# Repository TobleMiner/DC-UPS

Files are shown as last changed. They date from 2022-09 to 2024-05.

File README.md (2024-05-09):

DC uninterruptible power supply
===============================

This repository contains the design files for a DC uninterruptible power
supply well suited to run network appliances like small switches, home
routes and WLAN access points.

**I would not recommend ordering RevC yet as it is still untested.**  
**I would not recommend ordering RevB yet as there are still some issues with the current design.
See [Rev B issues](https://github.com/TobleMiner/DC-UPS#rev-b-issues) below.**

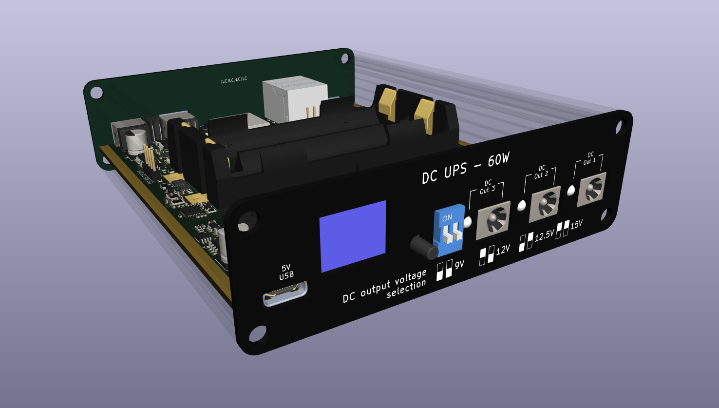
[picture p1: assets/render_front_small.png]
Render of the device


# Features

 - 3 DC outputs
 - Selectable output voltage (9V/12V/12.5V/15V)
 - USB-C power output (5V only, 3A)
 - Builtin, easy to replace batteries (2x Li-Ion 18650)
 - Builtin Prometheus-exporter with comprehensive metrics
 - Open Source firmware (ESP32-based, esp-idf framework)
 - Easy software updates via back USB port

# Construction

The mechanical construction of the DC UPS is based on 4 assemblies:
 - Hammond Manufacturing 1455L1201BK aluminum case
 - Main PCB
 - Aluminum core PCB front panel
 - Aluminum core PCB rear panel

The three PCBs have been optimized for manufacturing through JLCPCB.  
The main PCB is also designed to be suitable for assembly through JLCPCB.  

The relevant fabrication files are located in `fab`.  

For final assembly it is recommended to countersink the screw holes in
front and rear panel. This will allow the screws included with the case to
sit flush.

## Main PCB assembly

When using the JLCPCB assembly service only a very limited number of
components needs to be assembled by hand:
 - Battery holder B1
 - OLED display U17

## Thermals

For better thermal management I would highly recommend to install a thick,
generously sized thermal pad below U4 and L2 contacting the bottom case if
using the UPS DC outputs beyond 40W output power.

# Firmware

The DC UPS is running Open Source firmware. Firmware source can be found on
GitHub here: [https://github.com/TobleMiner/dc-ups-firmware](https://github.com/TobleMiner/dc-ups-firmware)

# Why?

For a long time I was running the core of my home network (a cable modem,
router and switch) off a normal line-interactive AC UPS.  
This was never ideal for a number of reasons. First of all the UPS was
using sealed lead acid batterys. The UPS did not seem to treat those too
kindly and ended up degrading them beyond the point of useful capacity
within 2 - 5 years, depending on quality of the battery.  
Also I noticed that the UPS was always getting somewhat warm, suggesting
high idle power consumption. In this particular setup the core network
components only use about 12W. The AC UPS alone already used 10W while
idle. Quite the waste of power.  
Another worrying factor was overall system reliability. With the AC UPS
there were three seperate wall warts in use, each powering a single
device. Powering all network compoenents with DC directly this is down
to just one wall wart at the power input of the UPS itself.  
Additionally I was never quite happy with the monitoring options offered
by the AC UPS. While it was equipped with a USB port for monitoring the
available metrics were minimal. The DC UPS offers an Ethernet port and
hosts a Prometheus exporter offering all kinds of metrics relating to
power input and output, temperatures, battery health and battery
management internals.  
Finally the DC UPS is a lot smaller than available AC UPS options. The
following picture shows a comparison between the AC UPS I have been using
before and the DC UPS:  

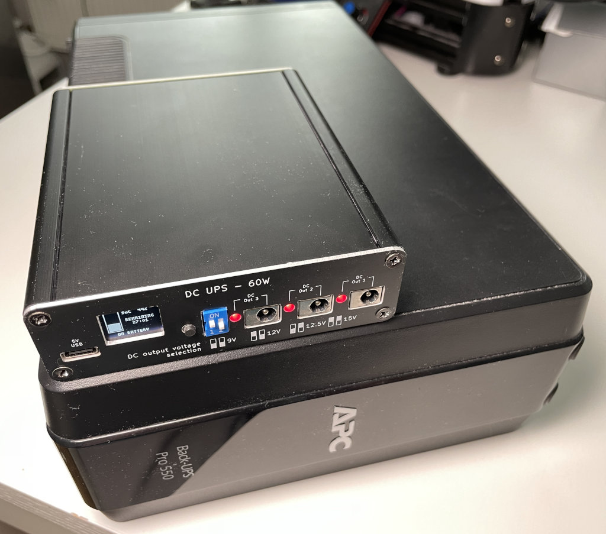
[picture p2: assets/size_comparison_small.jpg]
Size comparison between AC UPS and DC UPS. DC UPS is way smaller


# Rev B issues

Rev B is still more of a prototype than I'd like.
This is the list of currently know issues:
 - DCDC U4 startup is too slow on power failure, remove Q13
 - R47 and R48 are too high resistance for effective testing

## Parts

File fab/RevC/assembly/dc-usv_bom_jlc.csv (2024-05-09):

Comment | Designator | Footprint | LCSC Part Number
100nF | C1,C2,C3,C4,C5,C13,C16,C24,C25,C26,C30,C42,C45,C47,C48,C51,C59,C65,C66,C68,C96,C99,C101,C71,C73,C77,C78,C79,C81,C86,C88,C92,C93 | C_0402_1005Metric | C1525
2.2uF | C6,C53,C103 | C_0603_1608Metric | C23630
100nF HV | C7,C8,C9,C10,C11,C14,C34,C41,C43,C44,C46,C54,C72,C85,C87 | C_0603_1608Metric | C14663
1uF | C12,C17,C18,C27,C60,C62,C63,C64,C97,C98,C83 | C_0402_1005Metric | C52923
100pF | C15,C67 | C_0402_1005Metric | C1546
47nF HV | C19 | C_0603_1608Metric | C1622
10uF | C20,C21,C22,C23,C35,C36,C37 | C_0805_2012Metric | C15850
22uF | C28,C29,C31,C38,C39,C40,C94,C52,C55,C56,C57,C70,C74,C75 | C_0805_2012Metric | C602037
4.7uF | C32 | C_0402_1005Metric | C23733
680pF | C33 | C_0603_1608Metric | C1630
220uF | C49,C50,C80,C84 | CP_Elec_6.3x7.7 | C340768
18pF | C58,C76 | C_0402_1005Metric | C1549
470pF | C61 | R_0402_1005Metric | C1537
1nF 500V | C69,C82,C89 | C_1206_3216Metric | C35216
20pF | C90,C91 | C_0402_1005Metric | C1554
10uF LV | C100 | C_0402_1005Metric | C15525
4.7uF HV | C102 | C_0603_1608Metric | C19666
22nF | C104,C95,C105 | C_0402_1005Metric | C1532
1N4148WS | D1,D2,D3 | D_SOD-323 | C2128
BAV70 | D4 | SOT-23 | C68978
SS36 | D5 | D_SMC | C35722
P6SMB18CA | D6,D9,D10,D11 | D_SMB | C384916
RED | D8,D12,D13,D14 | LED_Indicator_RED_MHK1373CRBDT | C417352
B5819W | D15 | D_SOD-123 | C8598
P6SMB6.8CA | D16,D7 | D_SMB | C78395
YEL | D17,D21 | LED_0603_1608Metric | C72038
RED | D18,D22 | LED_0603_1608Metric | C2286
GRN | D19,D20 | LED_0603_1608Metric | C2994781
10A | F1 | Fuse_1206_3216Metric | C242475
5A | F2,F3,F4 | Fuse_1206_3216Metric | C377290
Output 2.0mm | J1,J2,J3 | BarrelJack_2.0mm_DC-044B | C397334
HanRun_HR911105A | J5 | RJ45_Hanrun_HR911105A | C12074
USB_C_Receptacle_USB2.0 | J6,J9 | USB_C_Receptacle_Palconn_UTC16-G | C167321
Input 2.0mm | J7 | BarrelJack_2.0mm_DC-044B | C397334
Input 2.5mm | J8 | BarrelJack_2.5mm_DC-044K-D025 | C963204
2.2uH | L1 | L_Taiyo-Yuden_MD-4040 | C98361
1uH | L2 | L_Bourns_SRP7028A_7.3x6.6mm | C439005
4.7uH | L3 | L_1008_2520Metric | C91237
4.7uH | L4 | L_Bourns_SRP7028A_7.3x6.6mm | C76857
AON7544 | Q1,Q3,Q4,Q5 | DFN-8-FET_3x3mm_P0.65mm | C315567
AO3401A | Q2,Q25 | SOT-23 | C15127
CSD17308Q3 | Q6,Q7 | DFN-8-FET_3x3mm_P0.65mm | C294987
AO4407A | Q8,Q10,Q19,Q21,Q23,Q32,Q35,Q38 | SOIC-8_3.9x4.9mm_P1.27mm | C167517
MMBT5401 | Q9,Q24 | SOT-23 | C8326
MMBT3904 | Q12,Q18,Q28,Q29,Q30,Q33,Q36 | SOT-23 | C20526
AO3400A | Q17 | SOT-23 | C20917
2N7002 | Q26,Q11,Q14,Q15,Q16,Q20,Q22,Q31,Q34,Q37 | SOT-23 | C8545
1mR | R1 | R_1206_3216Metric | C76287
100R | R2,R3,R130,R69,R122,R123,R99,R100 | R_0402_1005Metric | C25076
100R 0805 | R4,R5,R11 | R_0805_2012Metric | C17408
10MR | R6,R10,R13 | R_0402_1005Metric | C26082
300R | R7 | R_1206_3216Metric | C17887
5.1k | R8,R9,R12,R18,R22,R120,R124,R125,R97,R98 | R_0402_1005Metric | C25905
10k | R14,R95,R128,R129,R20,R119,R121,R93,R51,R53,R56,R57,R58,R60,R61,R62,R63,R65,R118,R127,R132,R83,R84,R126,R103,R113,R114,R115 | R_0402_1005Metric | C25744
100kR | R15,R26,R27,R29,R31,R33,R35,R41,R46,R49,R50,R94,R131,R52,R54,R59,R74,R116,R76,R77,R86,R87,R101,R102,R104,R105,R106,R107,R108,R109,R110,R111,R112 | R_0402_1005Metric | C25741
39kR | R16 | R_0402_1005Metric | C25783
18kR | R17,R21 | R_0402_1005Metric | C25762
10mR | R19,R25,R42,R43,R81,R90 | R_0805_2012Metric | C270927
10R | R23,R24 | R_0402_1005Metric | C25077
150k | R28 | R_0402_1005Metric | C25755
56kR | R30,R92 | R_0402_1005Metric | C25796
47kR | R32 | R_0603_1608Metric | C25819
180kR | R34 | R_0603_1608Metric | C22827
220kR | R36 | R_0402_1005Metric | C25767
1R | R37,R38,R44,R45,R80,R82,R89,R91 | R_0402_1005Metric | C25086
750kR | R39 | R_0603_1608Metric | C23240
15kR | R40 | R_0402_1005Metric | C25756
50R | R47,R48 | R_2512_6332Metric | C25487
22kR | R55 | R_0402_1005Metric | C25768
1.5kR | R64,R79 | R_0402_1005Metric | C25867
50R | R66,R68,R70,R71 | R_0402_1005Metric | C25120
12kR | R67,R78 | R_0402_1005Metric | C25752
330R | R72,R73 | R_0402_1005Metric | C25104
100kR | R75,R85,R96 | R_1206_3216Metric | C17900
10R | R88 | R_1206_3216Metric | C17903
390kR | R117 | R_0603_1608Metric | C23150
SW_DIP_x02 | SW1 | PinHeader_2x02_P2.54mm_Vertical | C692490
SW_Push | SW2 | x-1825027-x | C266183
10k | TH1,TH2 | R_0402_1005Metric | C279801
BQ40z50-R2 | U1 | VQFN-32-4.1x4.1-EP-1.4 | C179743
LM75B | U2,U7,U13 | MSOP-8_3x3mm_P0.65mm | C2837470
BQ24715 | U3 | QFN-20-1EP_3.5x3.5mm_P0.5mm_EP2x2mm_ThermalVias | C276341
TPS61178x | U4 | VSON-HR-13 | C127918
INA219AxD | U5,U6,U14,U15 | SOIC-8_3.9x4.9mm_P1.27mm | C138706
SY8120B1ABC | U8 | SOT-23-6 | C88474
ESP32-WROOM-32E | U9 | ESP32-WROOM-32 | C701342
LAN8720A | U10 | QFN-24-1EP_4x4mm_P0.5mm_EP2.6x2.6mm | C45223
74HC595 | U11 | SOIC-16_3.9x9.9mm_P1.27mm | C5947
SY8105 | U12 | TSOT-23-6 | C178247
CH340C | U16 | SOIC-16_3.9x9.9mm_P1.27mm | C84681
N066-6448TSWEG03-H28 | U17 | N066-6448TSWEG03-H28 | C2890608
SRV05-4 | U18 | SOT-23-6 | C85364

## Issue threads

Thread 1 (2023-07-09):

Provide header for unused GPIO

t-aus-m, 2023-07-09:
Hello there,

I really like the idea of this UPS, and I'd like to build it myself someday. However, I think there is one feature that is missing that would make this project even more versatile: As fas as I understood the schematics, there are still unused GPIOs left on the ESP32 that could be used to extend the use of the device even further.
Would it be possible to add a header, maybe even accessible from the outside to the device? For example, I'd use this header to be able to safely shut down my NAS in the event that the UPS is nearly empty.

Thanks for that awesome project!
Cheers

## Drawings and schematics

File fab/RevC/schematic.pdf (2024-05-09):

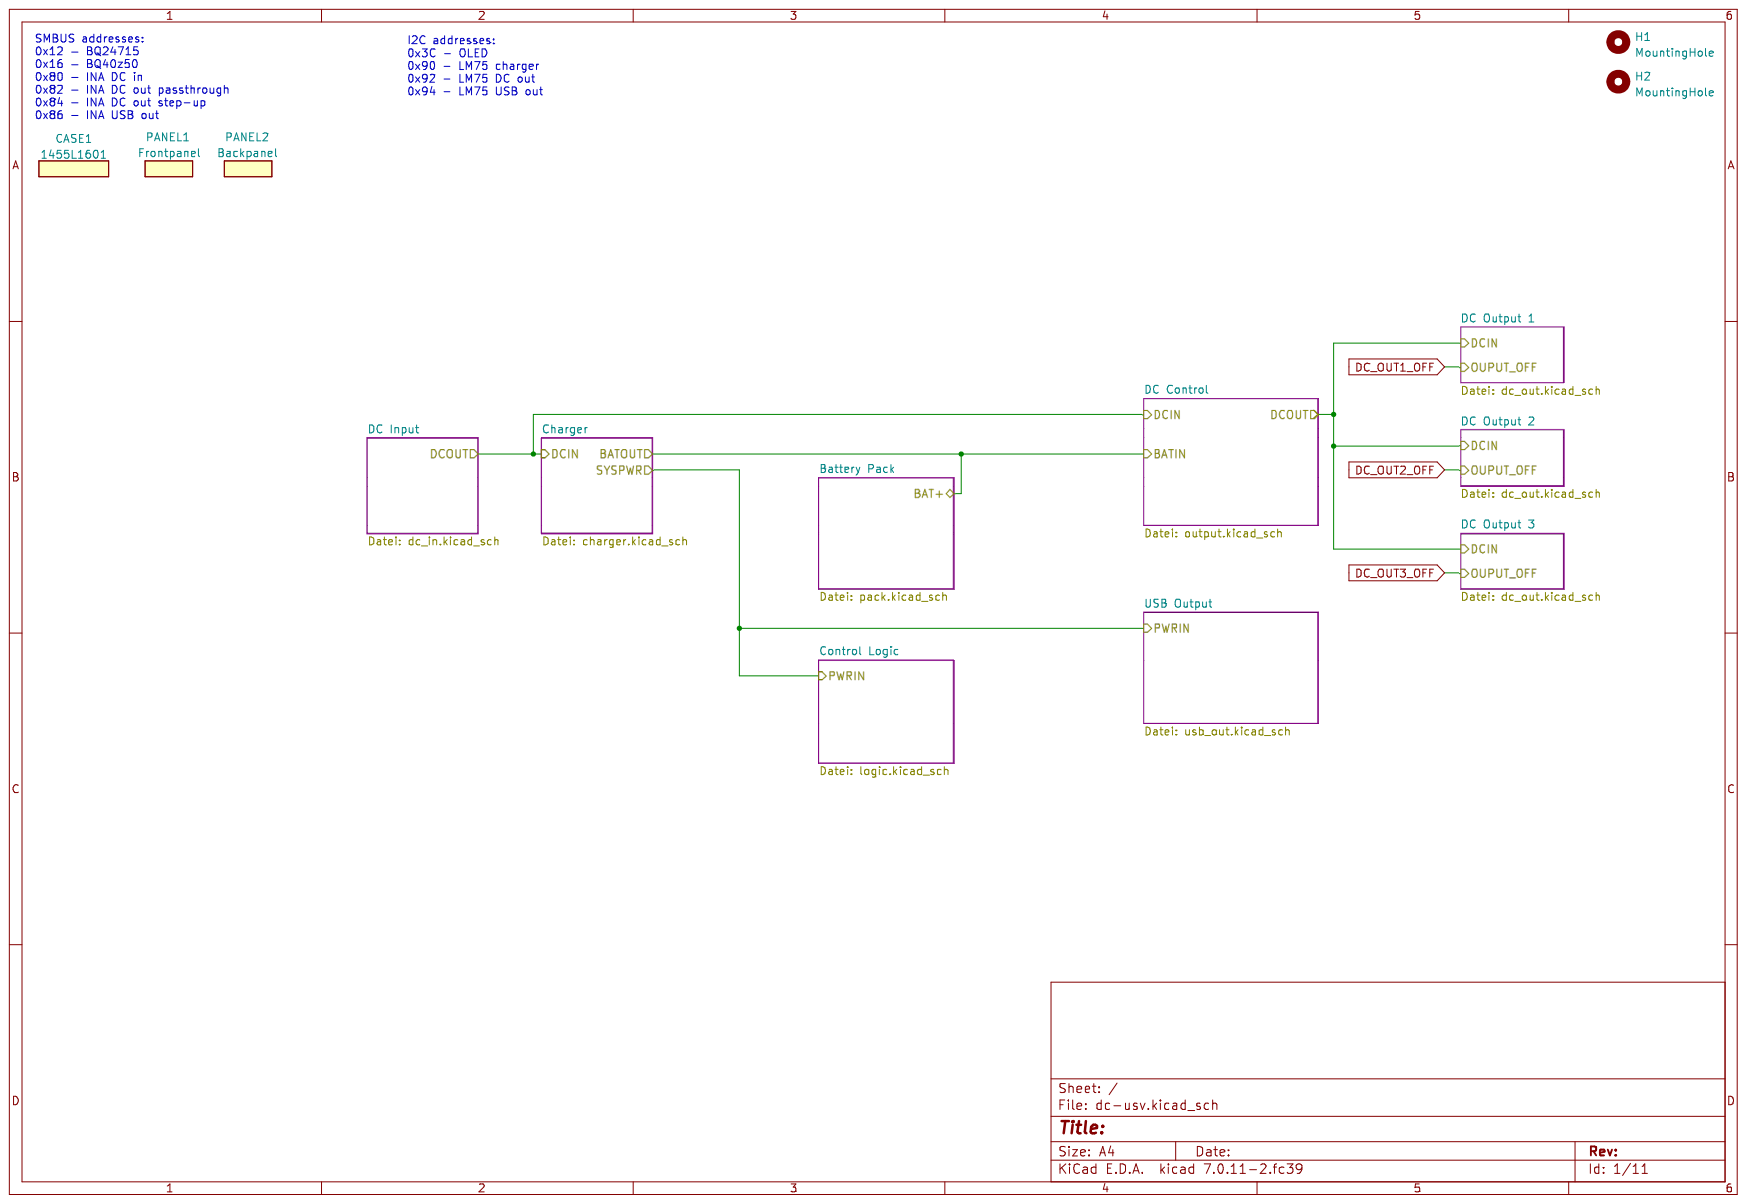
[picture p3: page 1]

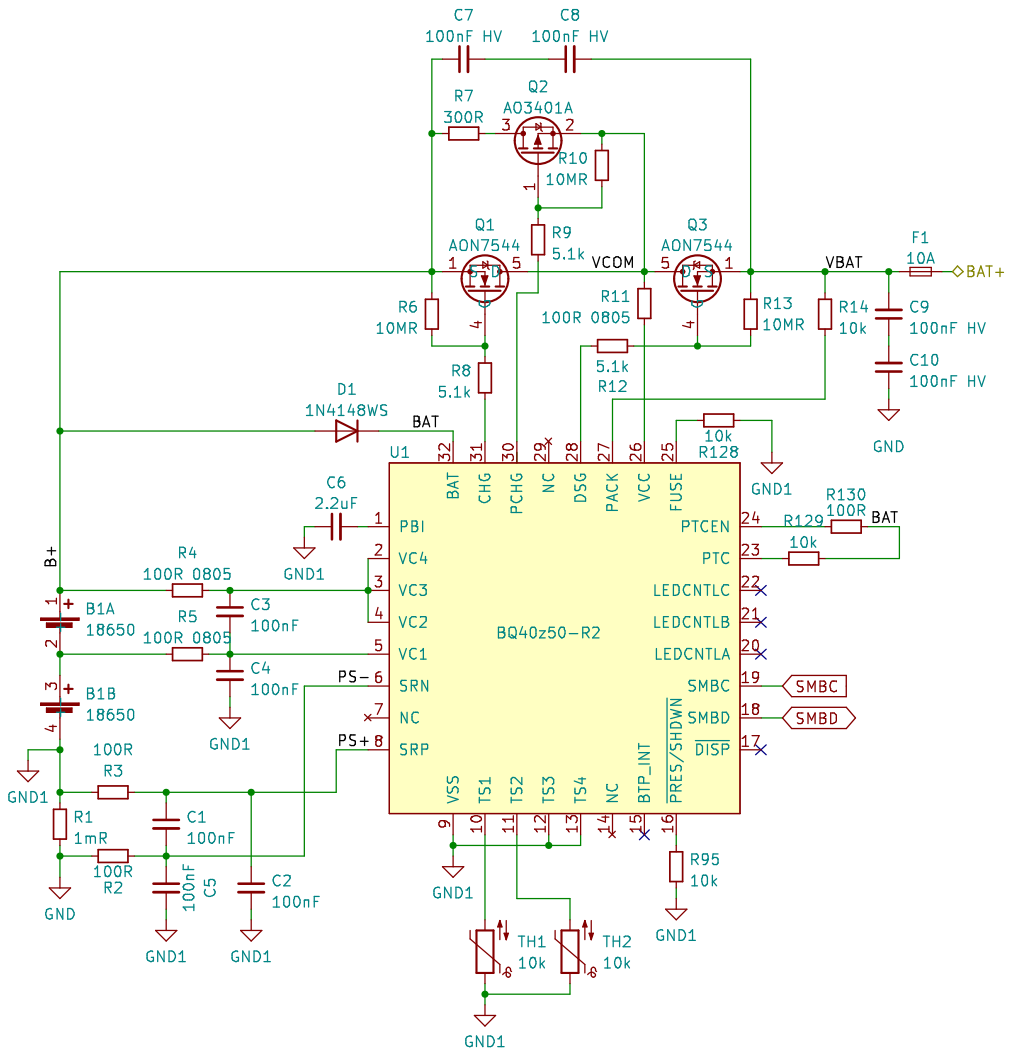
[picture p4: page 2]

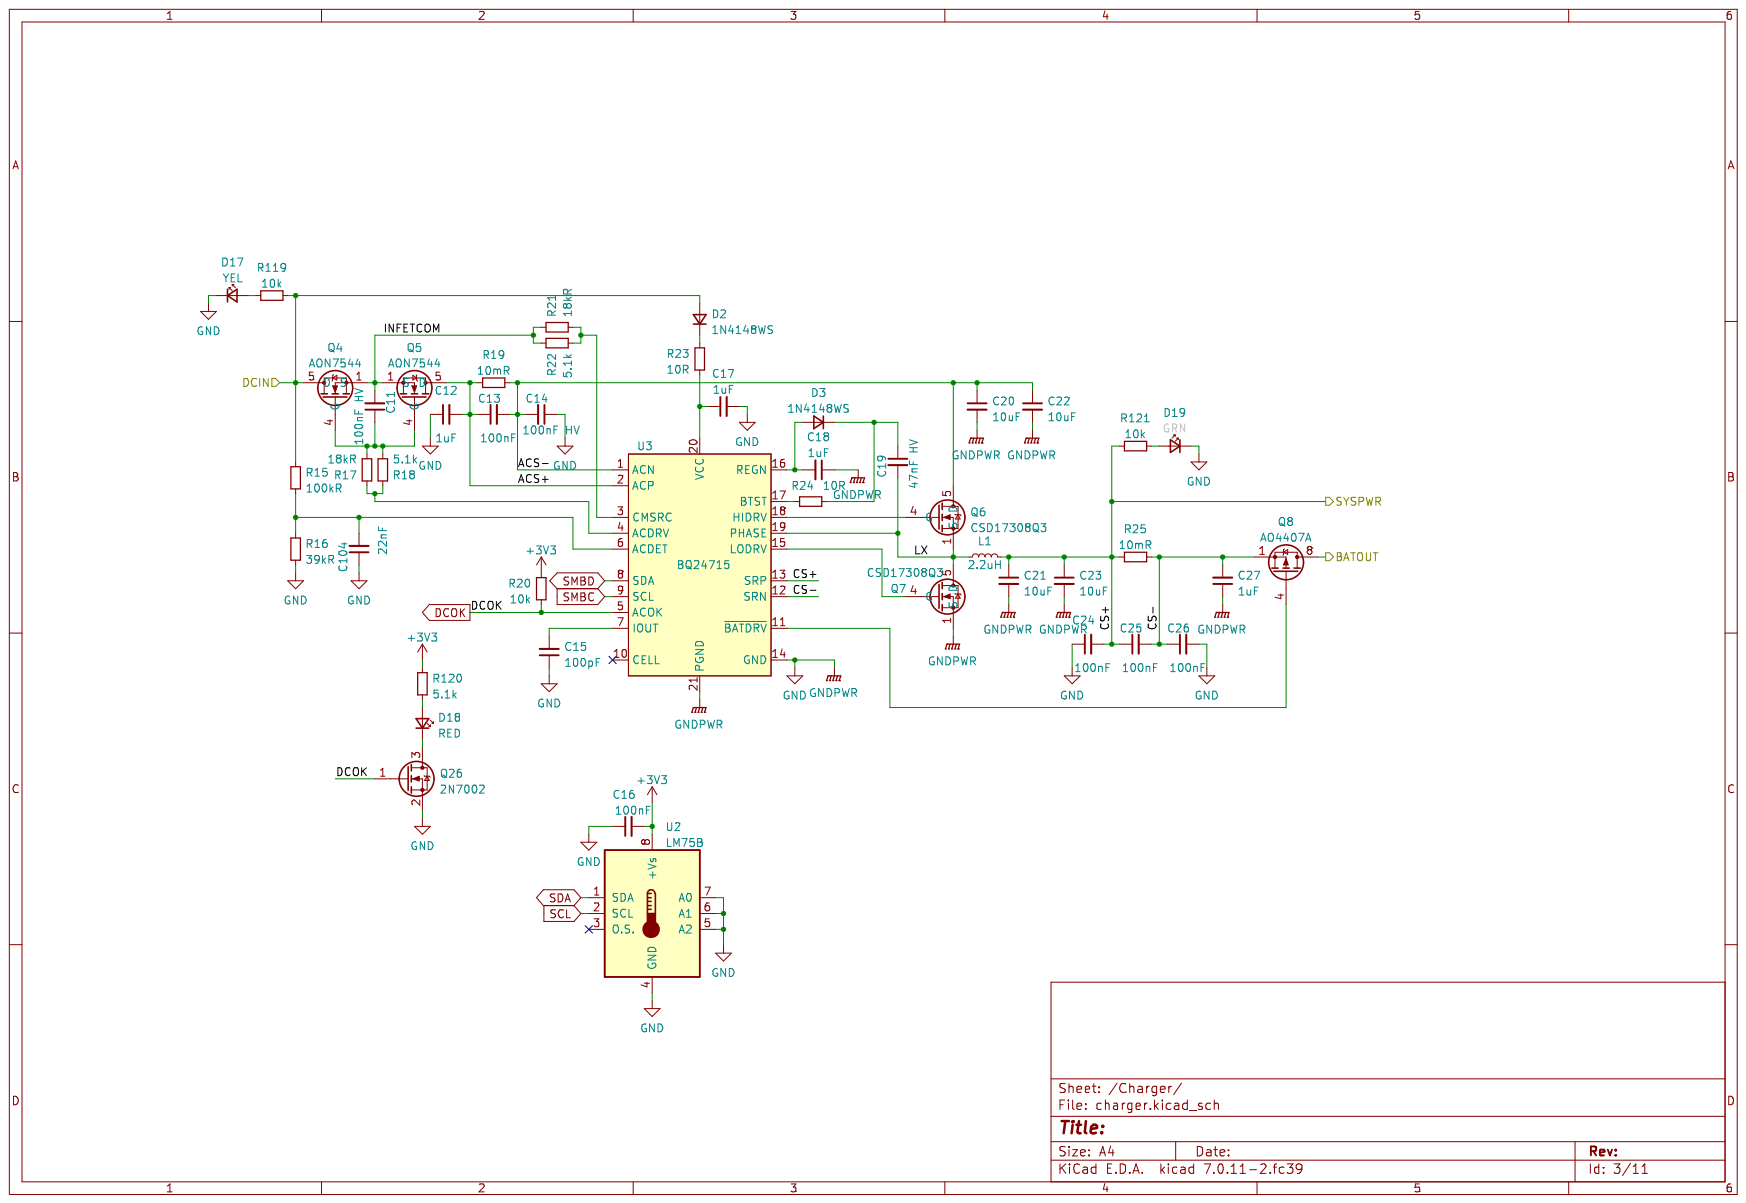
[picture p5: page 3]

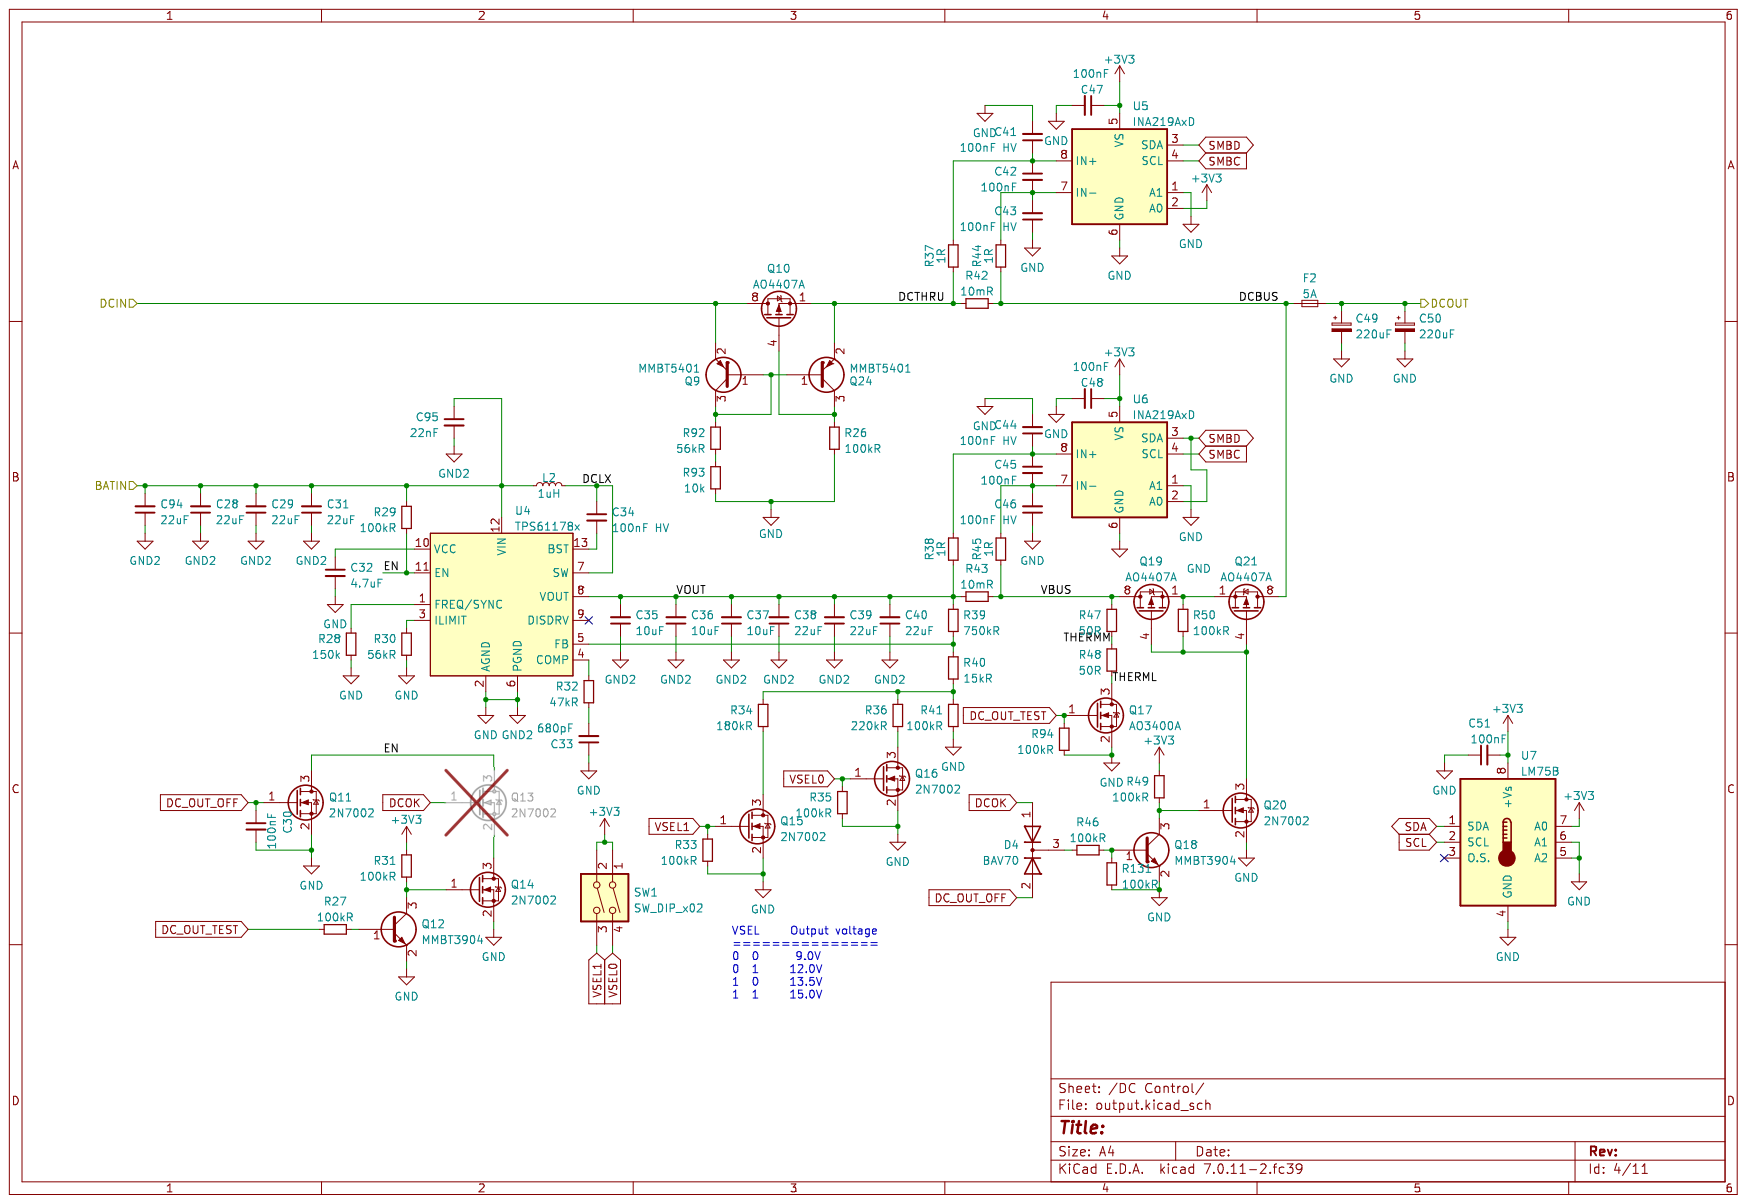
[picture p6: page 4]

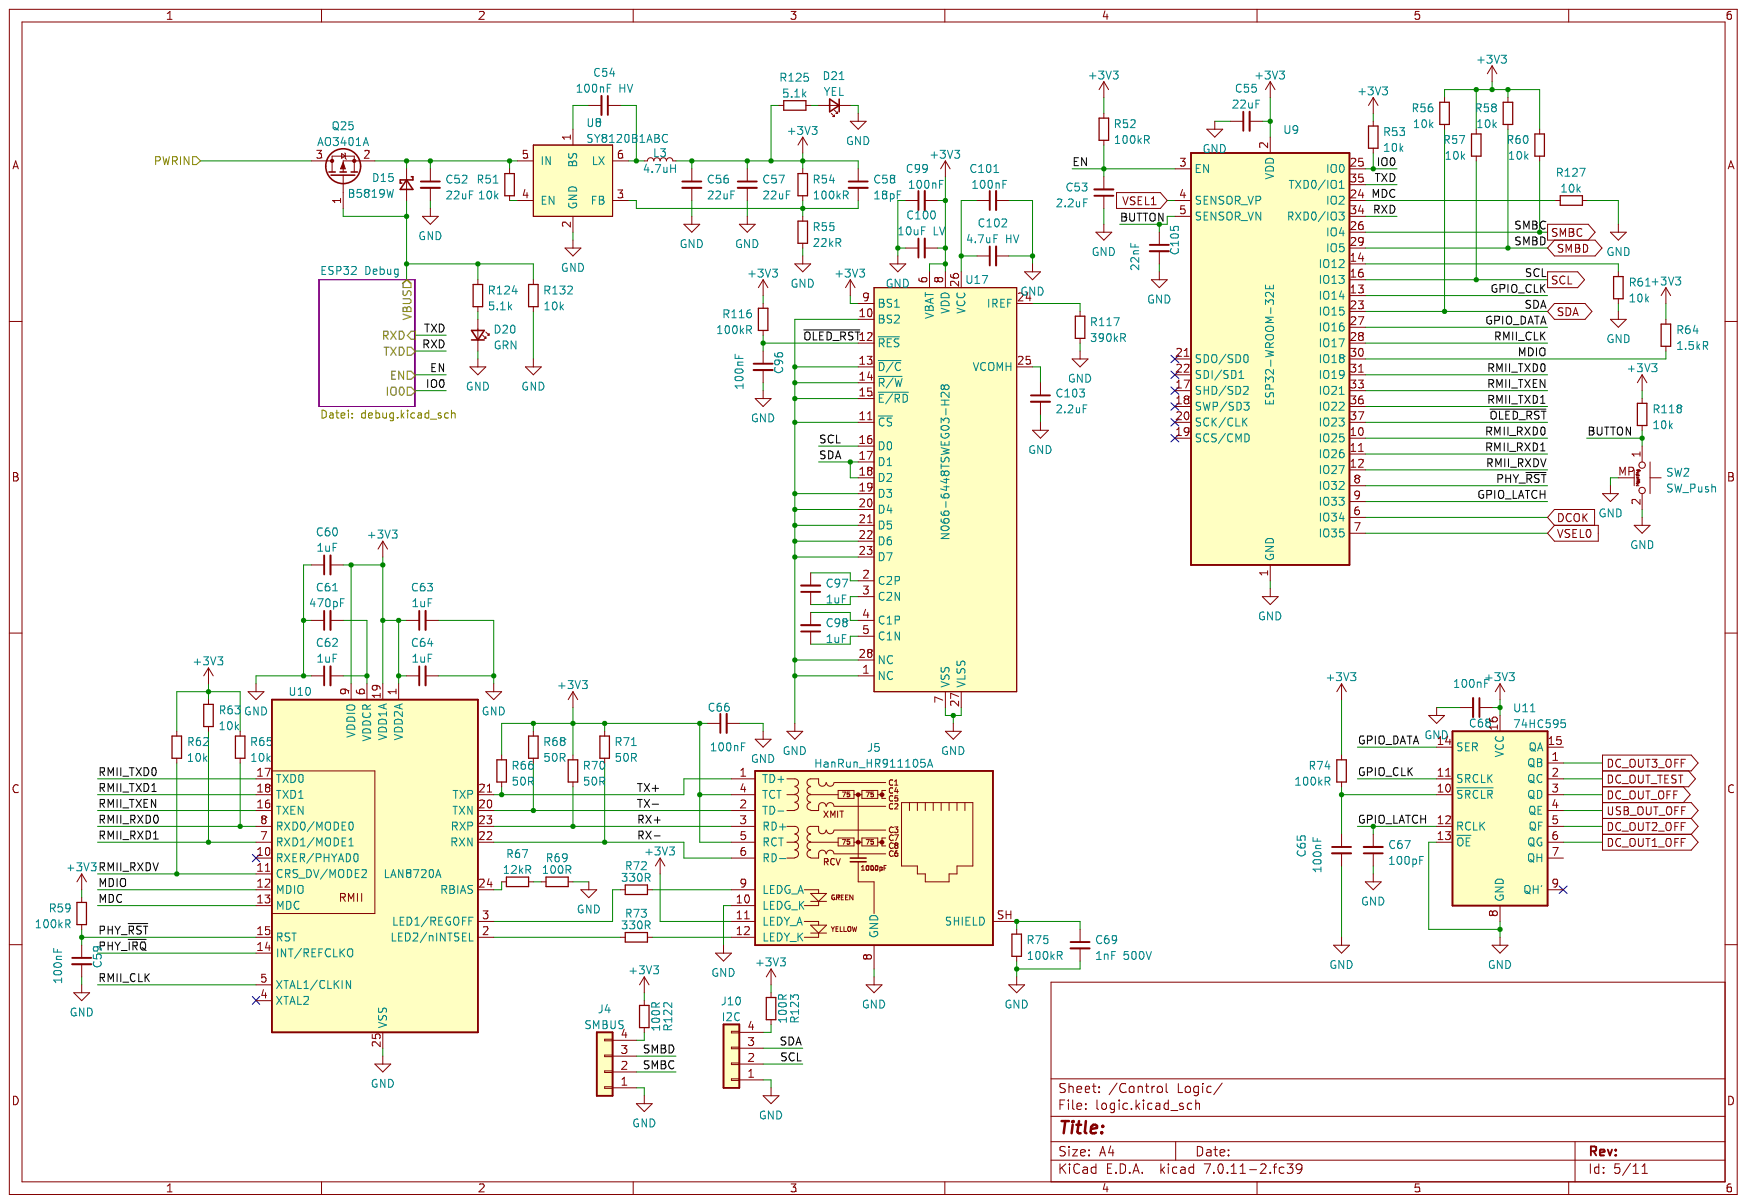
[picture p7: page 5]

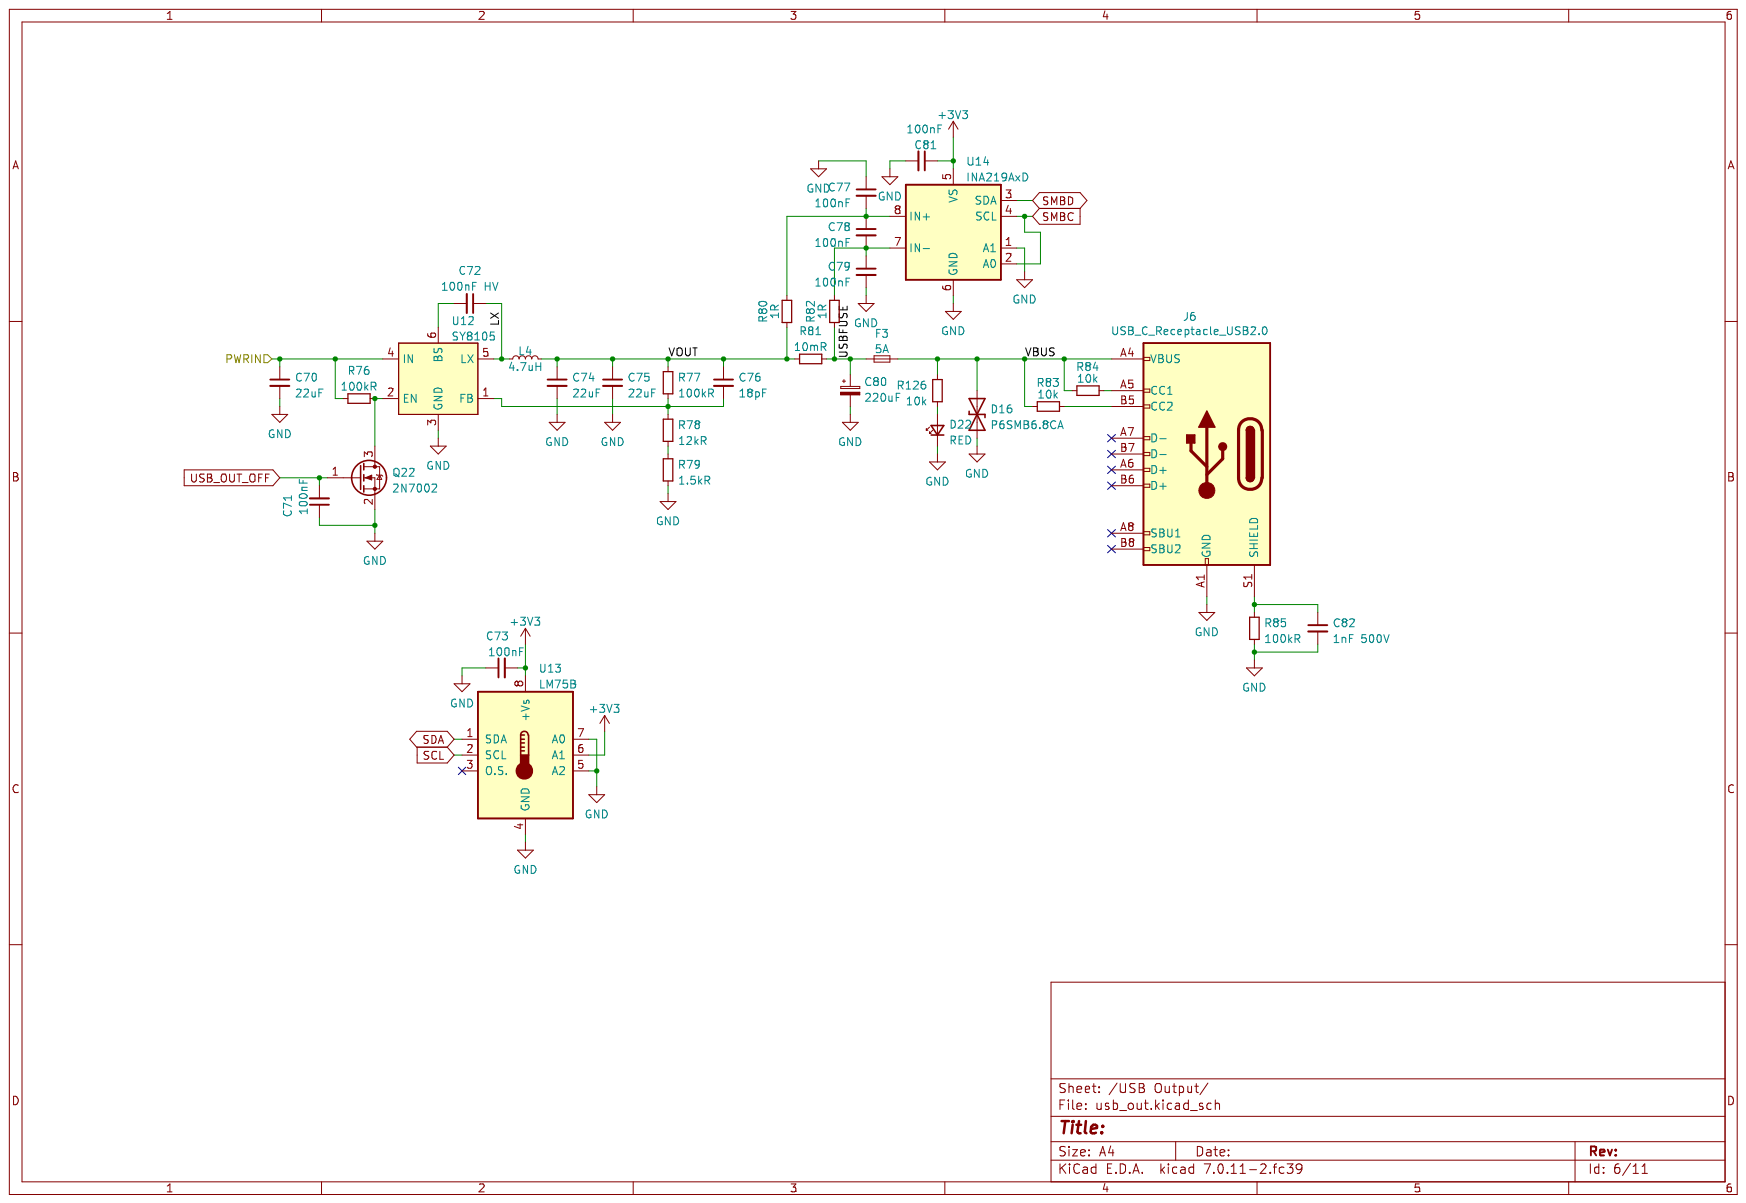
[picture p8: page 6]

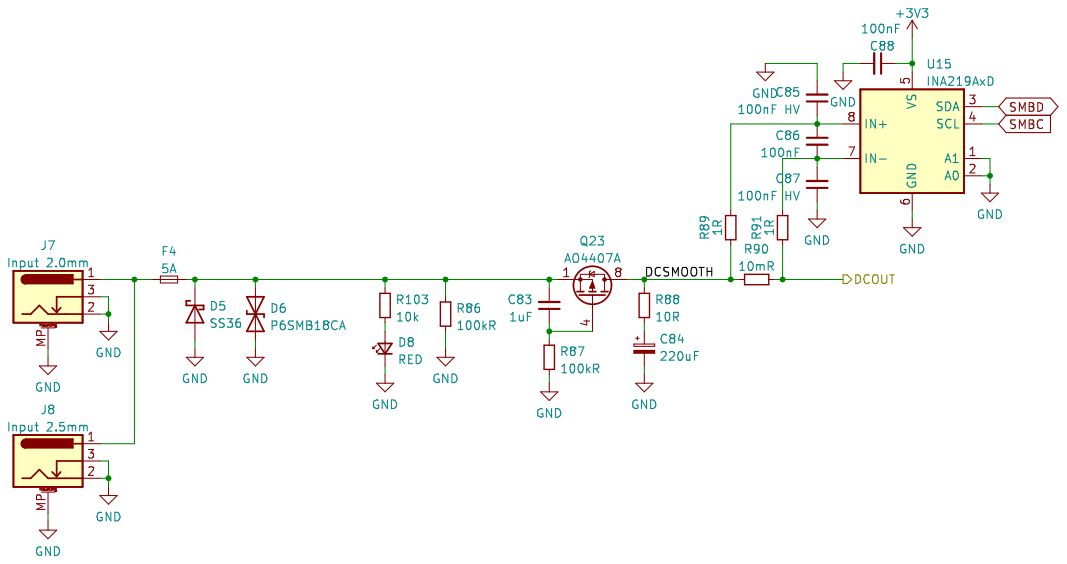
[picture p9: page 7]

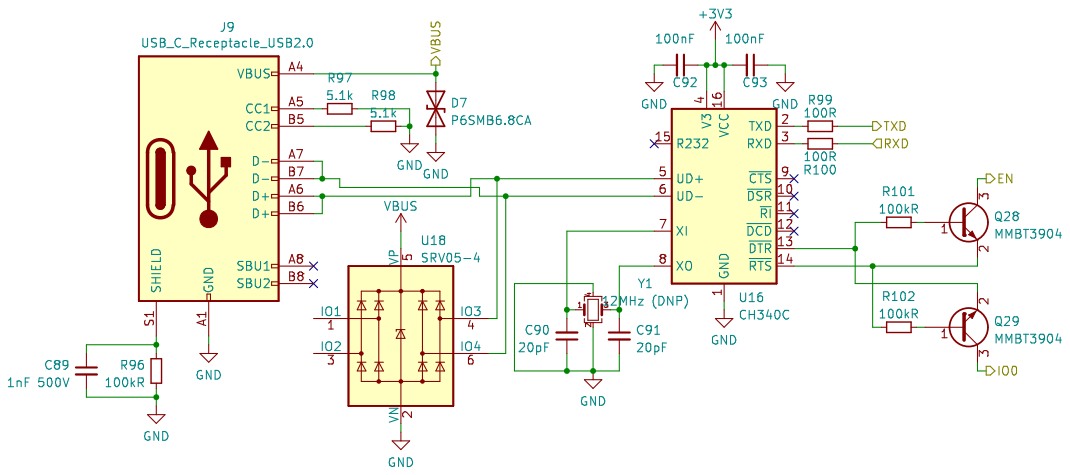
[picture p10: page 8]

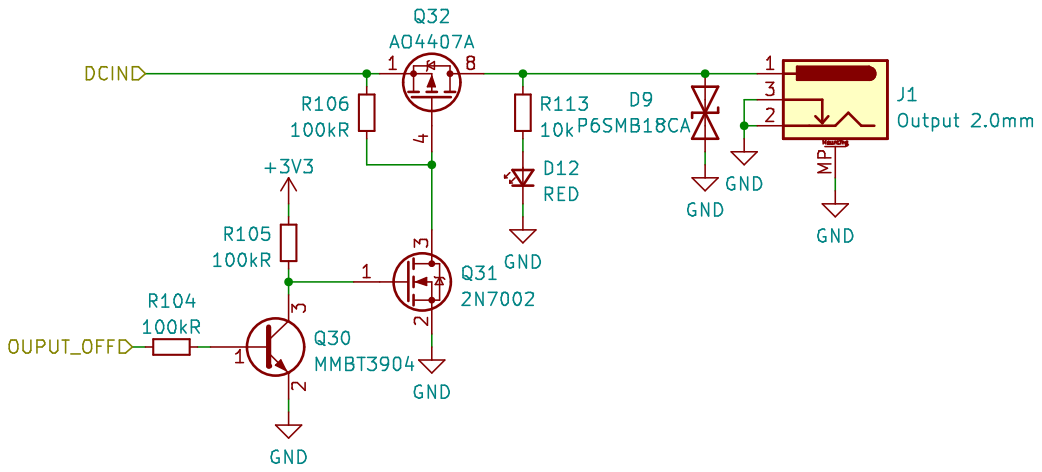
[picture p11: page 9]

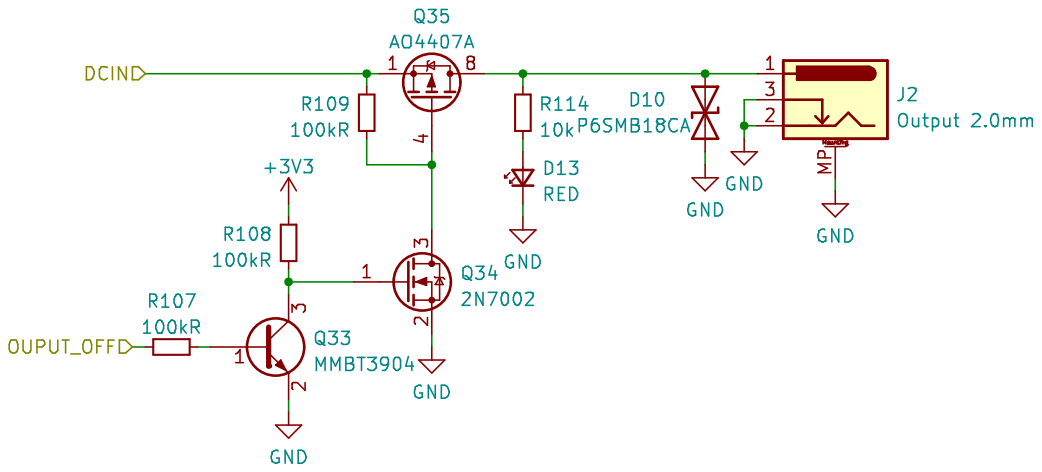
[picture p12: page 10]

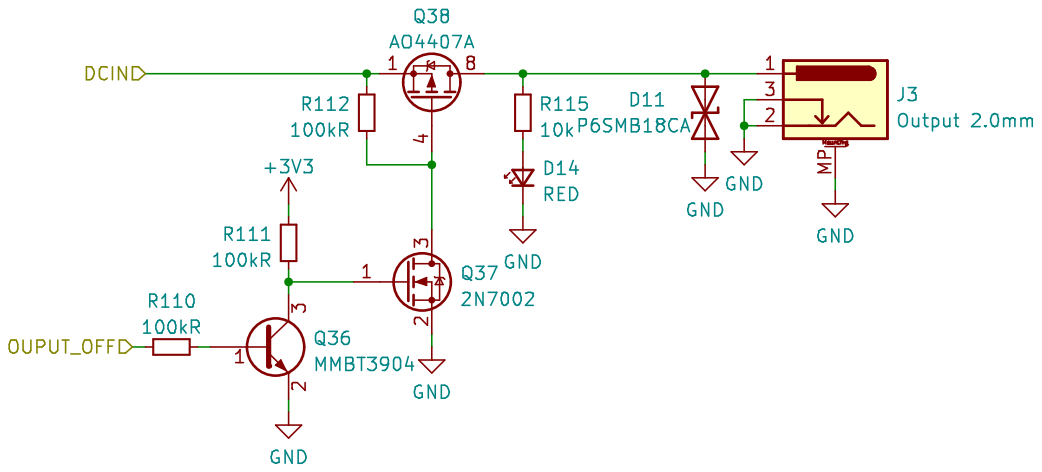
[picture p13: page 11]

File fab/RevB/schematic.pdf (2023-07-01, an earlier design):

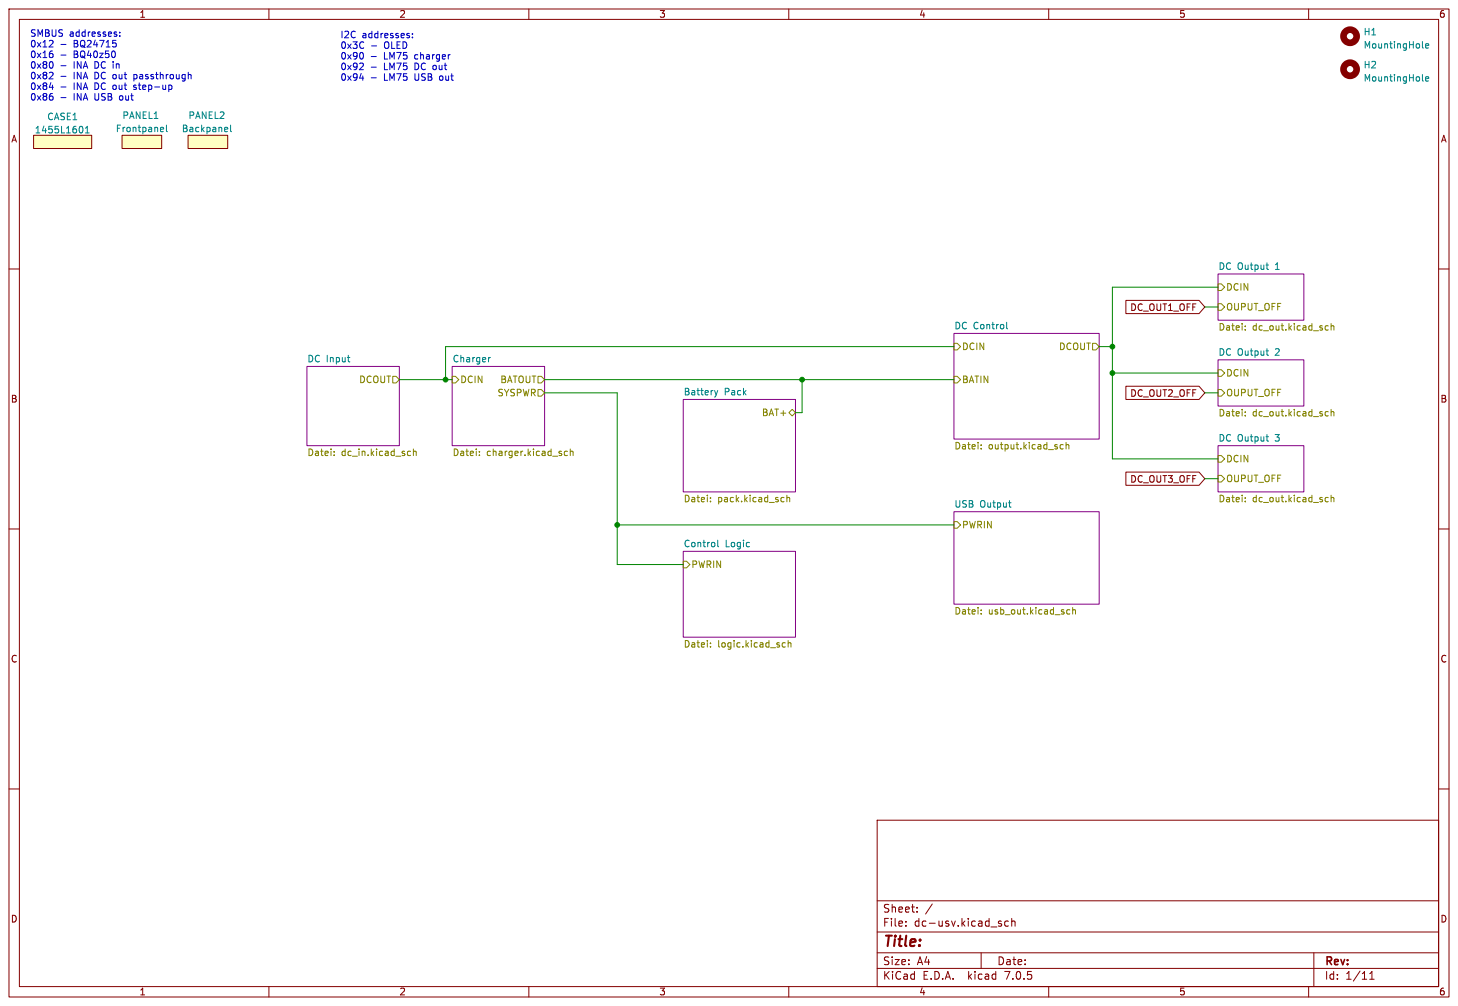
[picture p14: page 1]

0x80 - INA DC in
0x82 - INA DC out passthrough
0x84 - INA DC out step-up
0x86 - INA USB out

0x90 - LM75 charger 0x92 - LM75 DC out 0x94 - LM75 USB out

DC Output 1 Datei: dc_out.kicad_sch OUPUT_OFF DCIN
USB Output Datei: usb_out.kicad_sch DCIN
DC Output 2 Datei: dc_out.kicad_sch PWRIN

DC Output 3 Datei: dc_out.kicad_sch OUPUT_OFF DCIN

Id: 1/11 Title: File: dc-usv.kicad_sch Sheet: /



Id: 3/11 Title: File: charger.kicad_sch Sheet: /Charger/ GND GND


2 3 GND2 U4 TPS61178x FREQ/SYNC 1 VCC 10 EN 11 VIN 12 BST 13 AGND


2 SCK/CLK 20 SDO/SD0 21 SDI/SD1 22
GND

U17 N066-6448TSWEG03-H28 NC 1 BS2 10 ~{CS} 11 ~{RES} 12 ~{D/C} 13 ~{R/W} 14 ~{E/RD} 15 D0 16 D1 17 D2 18 D3 19 C2P 2 D4 20 D5 21 D6 22 D7 23




4 UD+ 5 UD- 6 XI 7 XO 8 ~{CTS}9 C90

1 ~{DSR} 10 ~{RI} 11 ~{DCD} 12 ~{DTR} 13 ~{RTS} 14 R232 15 VCC 16 TXD 2 RXD 3 V3

4 UD+ 5 UD- 6 XI 7 XO 8 ~{CTS}9 U16 CH340C


Id: 9/11 Title: File: dc_out.kicad_sch Sheet: /DC Output 1/


Id: 10/11 Title: File: dc_out.kicad_sch Sheet: /DC Output 2/


Id: 11/11 Title: File: dc_out.kicad_sch Sheet: /DC Output 3/

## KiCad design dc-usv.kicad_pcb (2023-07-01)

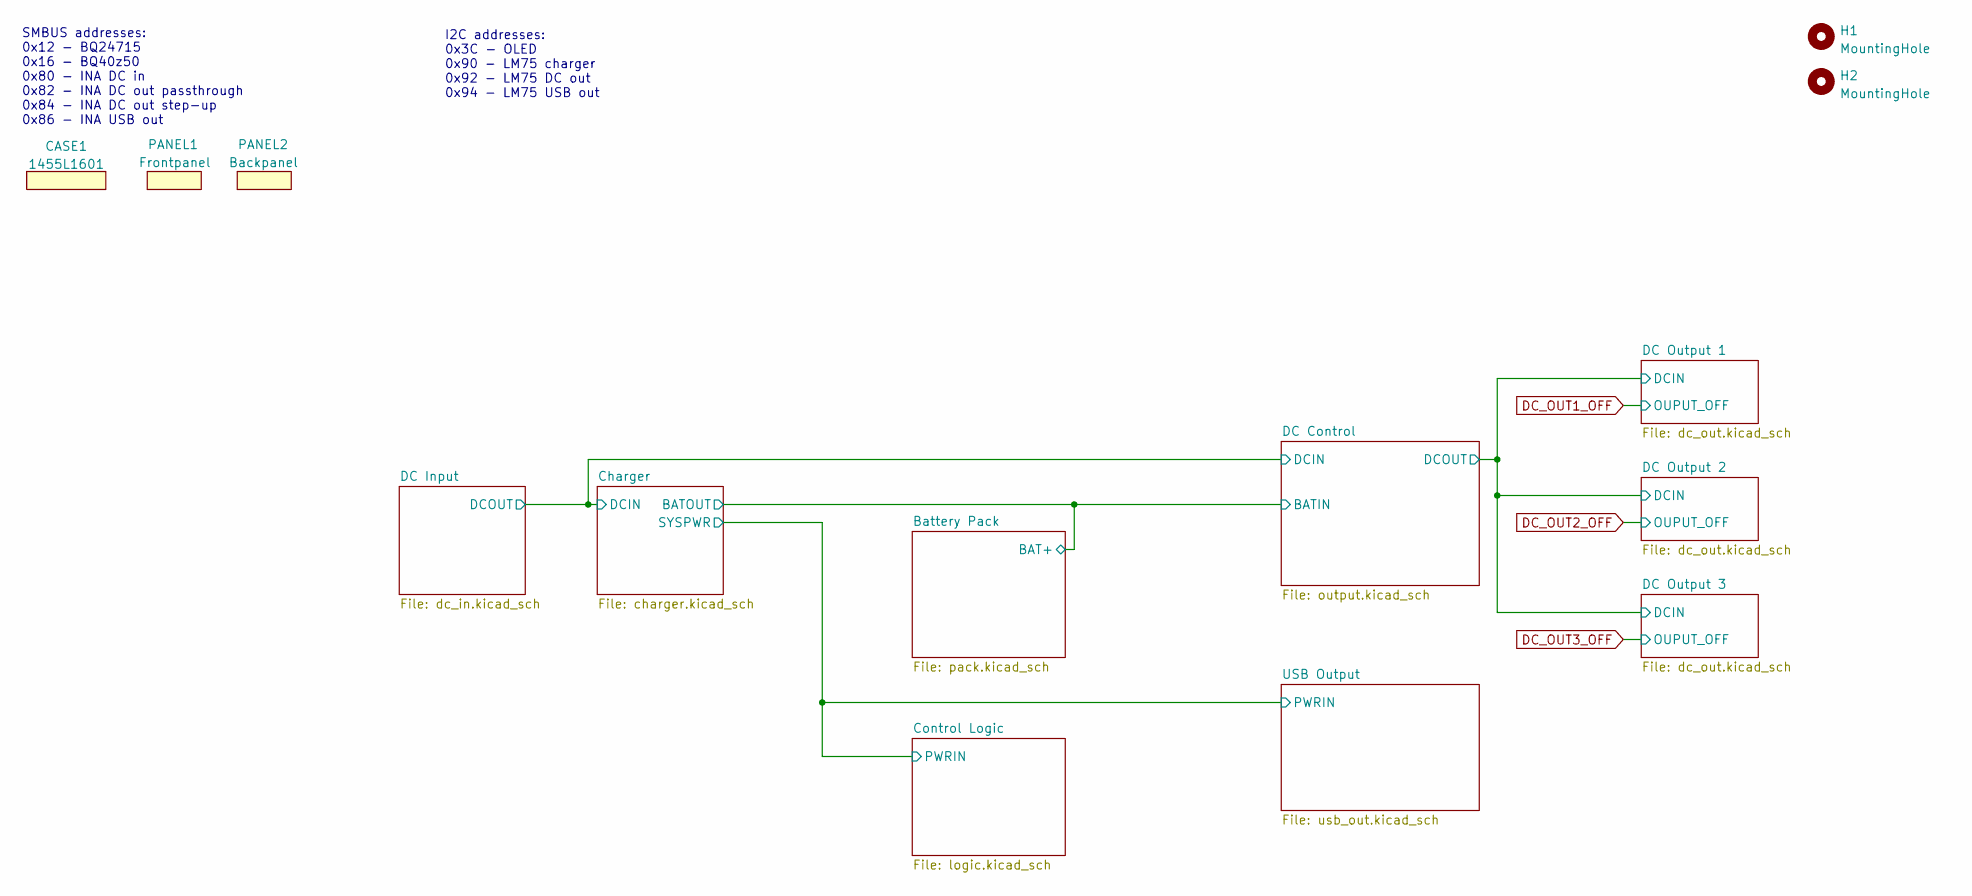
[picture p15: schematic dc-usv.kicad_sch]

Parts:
CASE1: 1455L1601
H1, H2: MountingHole; ToolingHole_JLCSMT
PANEL1: Frontpanel
PANEL2: Backpanel

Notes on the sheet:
I2C addresses: 0x3C - OLED 0x90 - LM75 charger 0x92 - LM75 DC out 0x94 - LM75 USB out
SMBUS addresses: 0x12 - BQ24715 0x16 - BQ40z50 0x80 - INA DC in 0x82 - INA DC out passthrough 0x84 - INA DC out step-up 0x86 - INA USB out

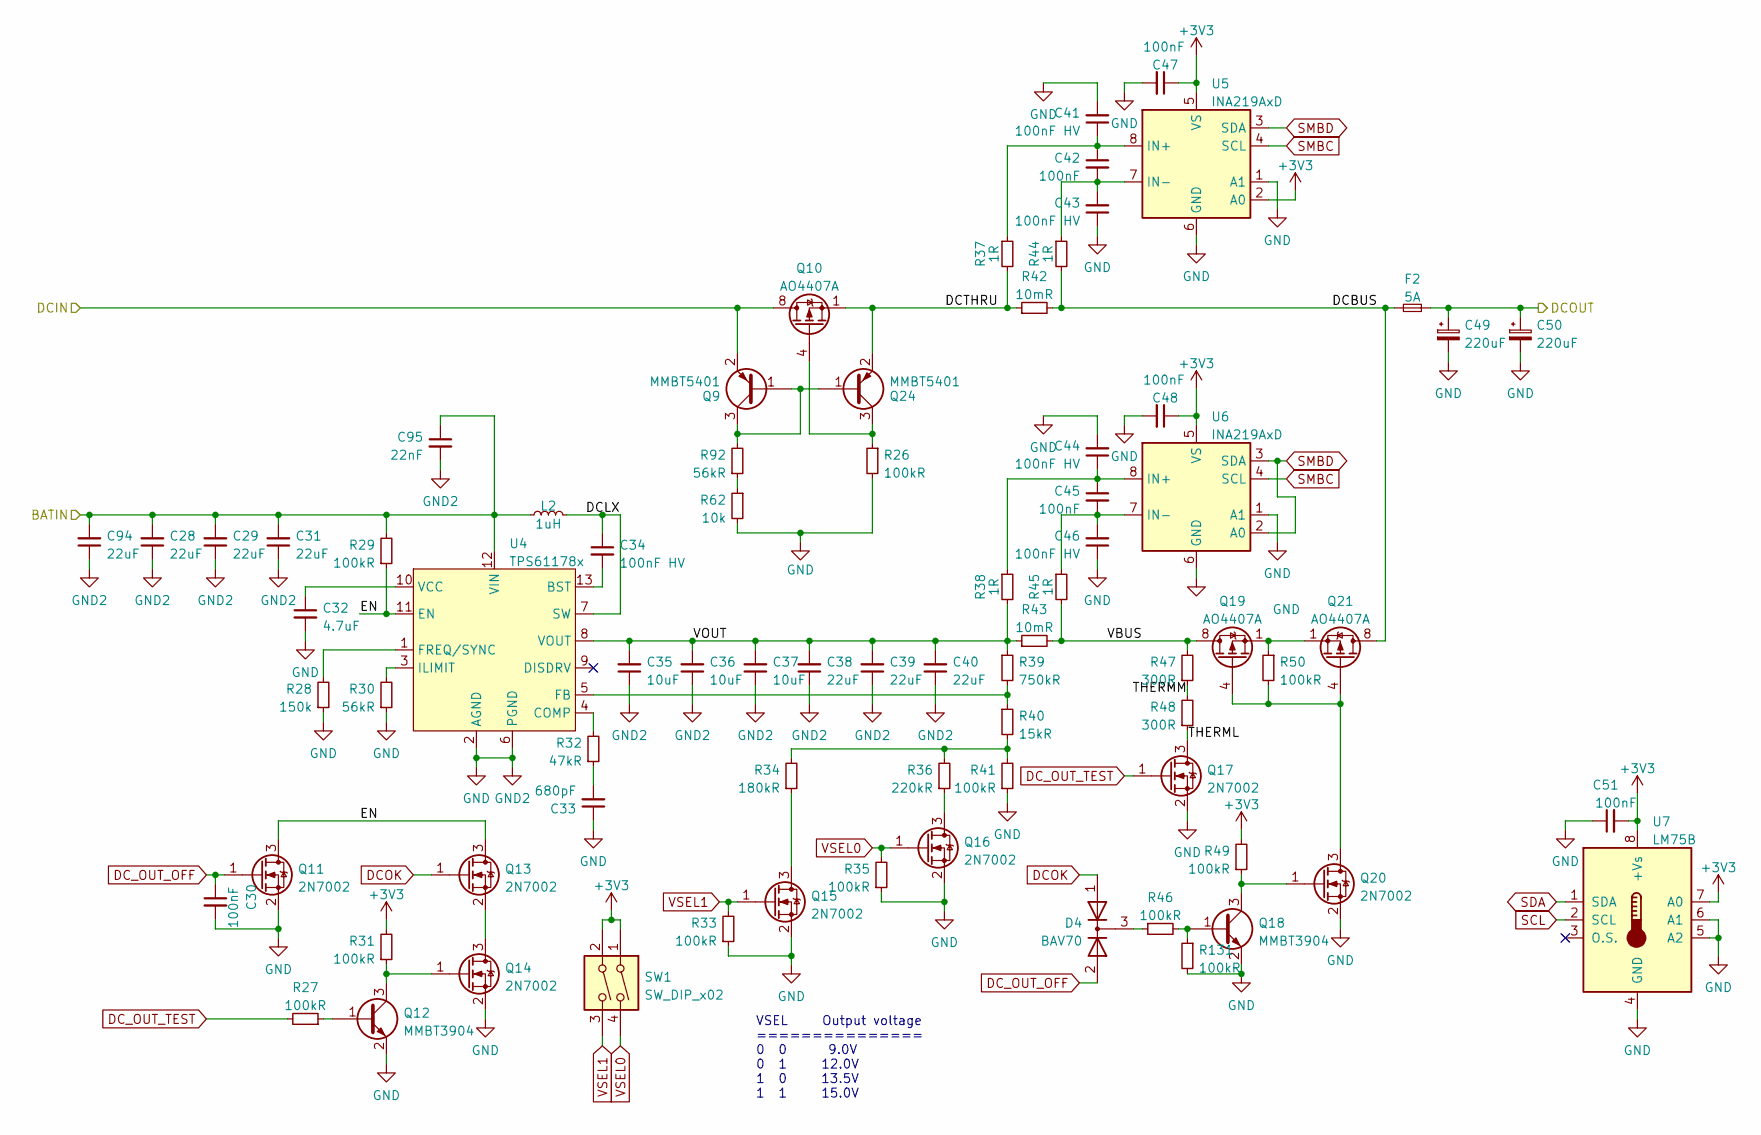
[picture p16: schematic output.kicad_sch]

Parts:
C28, C29, C31, C38, C39, C40, C94: 22uF; C_0805_2012Metric; LCSC C602037
C30, C42, C45, C47, C48, C51: 100nF; C_0402_1005Metric; LCSC C1525
C32: 4.7uF; C_0402_1005Metric; LCSC C23733
C33: 680pF; C_0603_1608Metric; LCSC C1630
C34, C41, C43, C44, C46: 100nF HV; C_0603_1608Metric; LCSC C14663
C35, C36, C37: 10uF; C_0805_2012Metric; LCSC C15850
C49, C50: 220uF; CP_Elec_6.3x7.7; LCSC C340768
C95: 22nF; C_0402_1005Metric; LCSC C1532
D4: BAV70; SOT-23; LCSC C68978
F2: 5A; Fuse_1206_3216Metric; LCSC C377290
L2: 1uH; L_Bourns_SRP7028A_7.3x6.6mm; LCSC C439005
Q9, Q24: MMBT5401; SOT-23; LCSC C8326
Q10, Q19, Q21: AO4407A; SOIC-8_3.9x4.9mm_P1.27mm; LCSC C167517
Q11, Q13, Q14, Q15, Q16, Q17, Q20: 2N7002; SOT-23; LCSC C8545
Q12, Q18: MMBT3904; SOT-23; LCSC C20526
R26, R27, R29, R31, R33, R35, R41, R46, R49, R50, R131: 100kR; R_0402_1005Metric; LCSC C25741
R28: 150k; R_0402_1005Metric; LCSC C25755
R30, R92: 56kR; R_0402_1005Metric; LCSC C25796
R32: 47kR; R_0603_1608Metric; LCSC C25819
R34: 180kR; R_0603_1608Metric; LCSC C22827
R36: 220kR; R_0402_1005Metric; LCSC C25767
R37, R38, R44, R45: 1R; R_0402_1005Metric; LCSC C25086
R39: 750kR; R_0603_1608Metric; LCSC C23240
R40: 15kR; R_0402_1005Metric; LCSC C25756
R42, R43: 10mR; R_0805_2012Metric; LCSC C270927
R47, R48: 300R; R_1206_3216Metric; LCSC C17887
R62: 10k; R_0402_1005Metric; LCSC C25744
SW1: SW_DIP_x02; PinHeader_2x02_P2.54mm_Vertical; LCSC C692490
U4: TPS61178x; VSON-HR-13; LCSC C127918
U5, U6: INA219AxD; SOIC-8_3.9x4.9mm_P1.27mm; LCSC C138706
U7: LM75B; MSOP-8_3x3mm_P0.65mm; LCSC C2837470

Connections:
/Battery Pack/BAT+: C28.2, C29.2, C31.2, C94.2, C95.1, L2.1, R29.2, U4.12 (VIN); also elsewhere on the board
/Charger/DCIN: Q9.2 (E), Q10.5 (D), Q10.6 (D), Q10.7 (D), Q10.8 (D); also elsewhere on the board
/DC Control/DCBUS: F2.2, Q21.5 (D), Q21.6 (D), Q21.7 (D), Q21.8 (D), R42.2, R44.2
/DC Control/DCLX: C34.1, L2.2, U4.7 (SW)
/DC Control/DCOUT: C49.1, C50.1, F2.1; also elsewhere on the board
/DC Control/DCTHRU: Q10.1 (S), Q10.2 (S), Q10.3 (S), Q24.2 (E), R37.2, R42.1
/DC Control/EN: Q11.3 (D), Q13.3 (D), R29.1, U4.11 (EN)
/DC Control/THERML: Q17.3 (D), R48.1
/DC Control/THERMM: R47.1, R48.2
/DC Control/VBUS: Q19.5 (D), Q19.6 (D), Q19.7 (D), Q19.8 (D), R43.2, R45.2, R47.2
/DC Control/VOUT: C35.2, C36.2, C37.2, C38.2, C39.2, C40.2, R38.2, R39.1, R43.1, U4.8 (VOUT)
DCOK: D4.1 (A), Q13.1 (G); also elsewhere on the board
DC_OUT_OFF: C30.1, D4.2 (A), Q11.1 (G); also elsewhere on the board
DC_OUT_TEST: Q17.1 (G), R27.2; also elsewhere on the board
unnamed: C33.2, R32.1
unnamed: D4.3 (K), R46.1
unnamed: Q10.4 (G), Q24.3 (C), R26.1
unnamed: Q12.1 (B), R27.1
unnamed: Q12.3 (C), Q14.1 (G), R31.1
unnamed: Q13.2 (S), Q14.3 (D)
unnamed: Q15.3 (D), R34.1
unnamed: Q16.3 (D), R36.1
unnamed: Q18.1 (B), R46.2, R131.1
unnamed: Q18.3 (C), Q20.1 (G), R49.1
unnamed: Q19.4 (G), Q20.3 (D), Q21.4 (G), R50.2
unnamed: Q19.1 (S), Q19.2 (S), Q19.3 (S), Q21.1 (S), Q21.2 (S), Q21.3 (S), R50.1
unnamed: Q9.1 (B), Q9.3 (C), Q24.1 (B), R92.2
unnamed: R34.2, R36.2, R40.2, R41.2
unnamed: C34.2, U4.13 (BST)
unnamed: R32.2, U4.4 (COMP)
unnamed: R39.2, R40.1, U4.5 (FB)
unnamed: R28.2, U4.1 (FREQ/SYNC)
unnamed: R30.2, U4.3 (ILIMIT)
unnamed: C32.1, U4.10 (VCC)
unnamed: C41.1, C42.1, R37.1, U5.8 (IN+)
unnamed: C42.2, C43.2, R44.1, U5.7 (IN-)
unnamed: C44.1, C45.1, R38.1, U6.8 (IN+)
unnamed: C45.2, C46.2, R45.1, U6.7 (IN-)
SCL: U7.2 (SCL); also elsewhere on the board
SDA: U7.1 (SDA); also elsewhere on the board
SMBC: U5.4 (SCL), U6.4 (SCL); also elsewhere on the board
SMBD: U5.3 (SDA), U6.2 (A0), U6.3 (SDA); also elsewhere on the board
VSEL0: Q16.1 (G), R35.2, SW1.4; also elsewhere on the board
VSEL1: Q15.1 (G), R33.2, SW1.3; also elsewhere on the board

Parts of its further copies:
R93: 10k; R_0402_1005Metric; LCSC C25744

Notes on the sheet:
VSEL Output voltage =============== 0 0 9.0V 0 1 12.0V 1 0 13.5V 1 1 15.0V

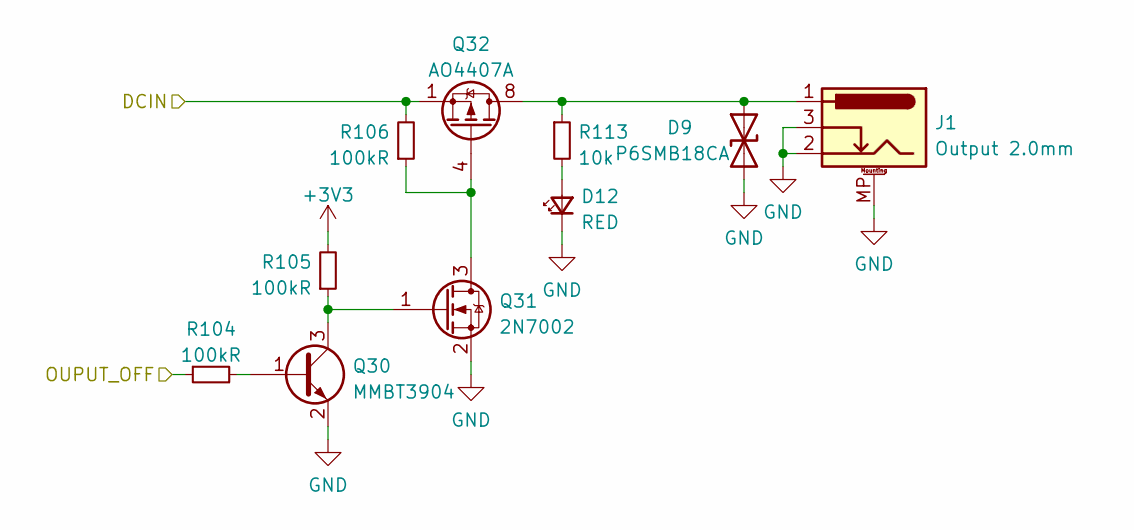
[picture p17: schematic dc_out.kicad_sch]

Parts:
D9: P6SMB18CA; D_SMB; LCSC C384916
D12: RED; LED_Indicator_RED_MHK1373CRBDT; LCSC C417352
J1: Output 2.0mm; BarrelJack_2.0mm_DC-044B; LCSC C397334
Q30: MMBT3904; SOT-23; LCSC C20526
Q31: 2N7002; SOT-23; LCSC C8545
Q32: AO4407A; SOIC-8_3.9x4.9mm_P1.27mm; LCSC C167517
R104, R105, R106: 100kR; R_0402_1005Metric; LCSC C25741
R113: 10k; R_0402_1005Metric; LCSC C25744

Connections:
/DC Control/DCOUT: Q32.1 (S), Q32.2 (S), Q32.3 (S), R106.2; also elsewhere on the board
DC_OUT1_OFF: R104.1; also elsewhere on the board
unnamed: D9.1 (A1), J1.1, Q32.5 (D), Q32.6 (D), Q32.7 (D), Q32.8 (D), R113.1
unnamed: D12.2 (A), R113.2
unnamed: Q30.1 (B), R104.2
unnamed: Q30.3 (C), Q31.1 (G), R105.1
unnamed: Q31.3 (D), Q32.4 (G), R106.1

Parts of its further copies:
D10, D11: P6SMB18CA; D_SMB; LCSC C384916
D13, D14: RED; LED_Indicator_RED_MHK1373CRBDT; LCSC C417352
J2, J3: Output 2.0mm; BarrelJack_2.0mm_DC-044B; LCSC C397334
Q33, Q36: MMBT3904; SOT-23; LCSC C20526
Q34, Q37: 2N7002; SOT-23; LCSC C8545
Q35, Q38: AO4407A; SOIC-8_3.9x4.9mm_P1.27mm; LCSC C167517
R107, R108, R109, R110, R111, R112: 100kR; R_0402_1005Metric; LCSC C25741
R114, R115: 10k; R_0402_1005Metric; LCSC C25744

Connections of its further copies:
/DC Control/DCOUT: Q35.1 (S), Q35.2 (S), Q35.3 (S), Q38.1 (S), Q38.2 (S), Q38.3 (S), R109.2, R112.2; also elsewhere on the board
DC_OUT2_OFF: R107.1; also elsewhere on the board
DC_OUT3_OFF: R110.1; also elsewhere on the board
unnamed: D10.1 (A1), J2.1, Q35.5 (D), Q35.6 (D), Q35.7 (D), Q35.8 (D), R114.1
unnamed: D11.1 (A1), J3.1, Q38.5 (D), Q38.6 (D), Q38.7 (D), Q38.8 (D), R115.1
unnamed: D13.2 (A), R114.2
unnamed: D14.2 (A), R115.2
unnamed: Q33.1 (B), R107.2
unnamed: Q33.3 (C), Q34.1 (G), R108.1
unnamed: Q34.3 (D), Q35.4 (G), R109.1
unnamed: Q36.1 (B), R110.2
unnamed: Q36.3 (C), Q37.1 (G), R111.1
unnamed: Q37.3 (D), Q38.4 (G), R112.1

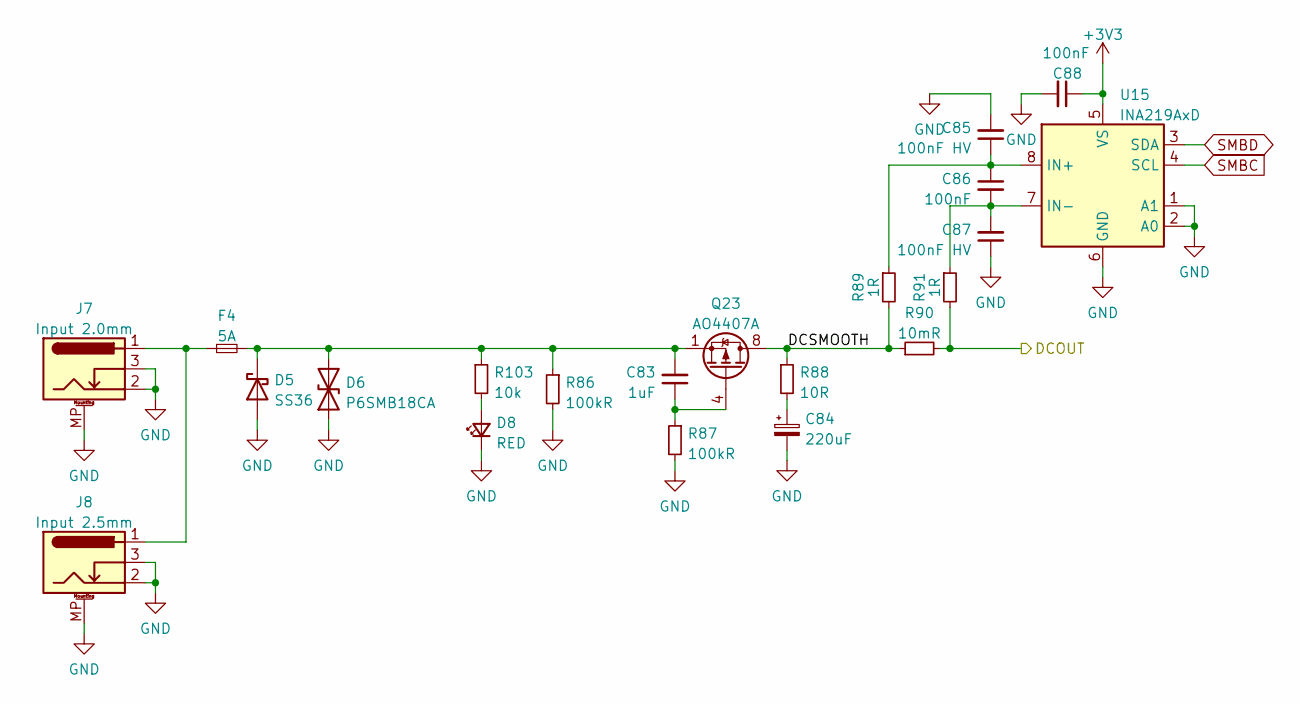
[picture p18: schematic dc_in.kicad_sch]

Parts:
C83: 1uF; C_0402_1005Metric; LCSC C52923
C84: 220uF; CP_Elec_6.3x7.7; LCSC C340768
C85, C87: 100nF HV; C_0603_1608Metric; LCSC C14663
C86, C88: 100nF; C_0402_1005Metric; LCSC C1525
D5: SS36; D_SMC; LCSC C35722
D6: P6SMB18CA; D_SMB; LCSC C384916
D8: RED; LED_Indicator_RED_MHK1373CRBDT; LCSC C417352
F4: 5A; Fuse_1206_3216Metric; LCSC C377290
J7: Input 2.0mm; BarrelJack_2.0mm_DC-044B; LCSC C397334
J8: Input 2.5mm; BarrelJack_2.5mm_DC-044K-D025; LCSC C963204
Q23: AO4407A; SOIC-8_3.9x4.9mm_P1.27mm; LCSC C167517
R86, R87: 100kR; R_0402_1005Metric; LCSC C25741
R88: 10R; R_1206_3216Metric; LCSC C17903
R89, R91: 1R; R_0402_1005Metric; LCSC C25086
R90: 10mR; R_0805_2012Metric; LCSC C270927
R103: 10k; R_0402_1005Metric; LCSC C25744
U15: INA219AxD; SOIC-8_3.9x4.9mm_P1.27mm; LCSC C138706

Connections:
/Charger/DCIN: R90.2, R91.2; also elsewhere on the board
/DC Input/DCSMOOTH: Q23.5 (D), Q23.6 (D), Q23.7 (D), Q23.8 (D), R88.1, R89.2, R90.1
unnamed: C84.1, R88.2
unnamed: C83.2, D5.1 (K), D6.2 (A2), F4.2, Q23.1 (S), Q23.2 (S), Q23.3 (S), R86.1, R103.1
unnamed: D8.2 (A), R103.2
unnamed: F4.1, J7.1, J8.1
unnamed: C83.1, Q23.4 (G), R87.1
unnamed: C85.1, C86.1, R89.1, U15.8 (IN+)
unnamed: C86.2, C87.2, R91.1, U15.7 (IN-)
SMBC: U15.4 (SCL); also elsewhere on the board
SMBD: U15.3 (SDA); also elsewhere on the board

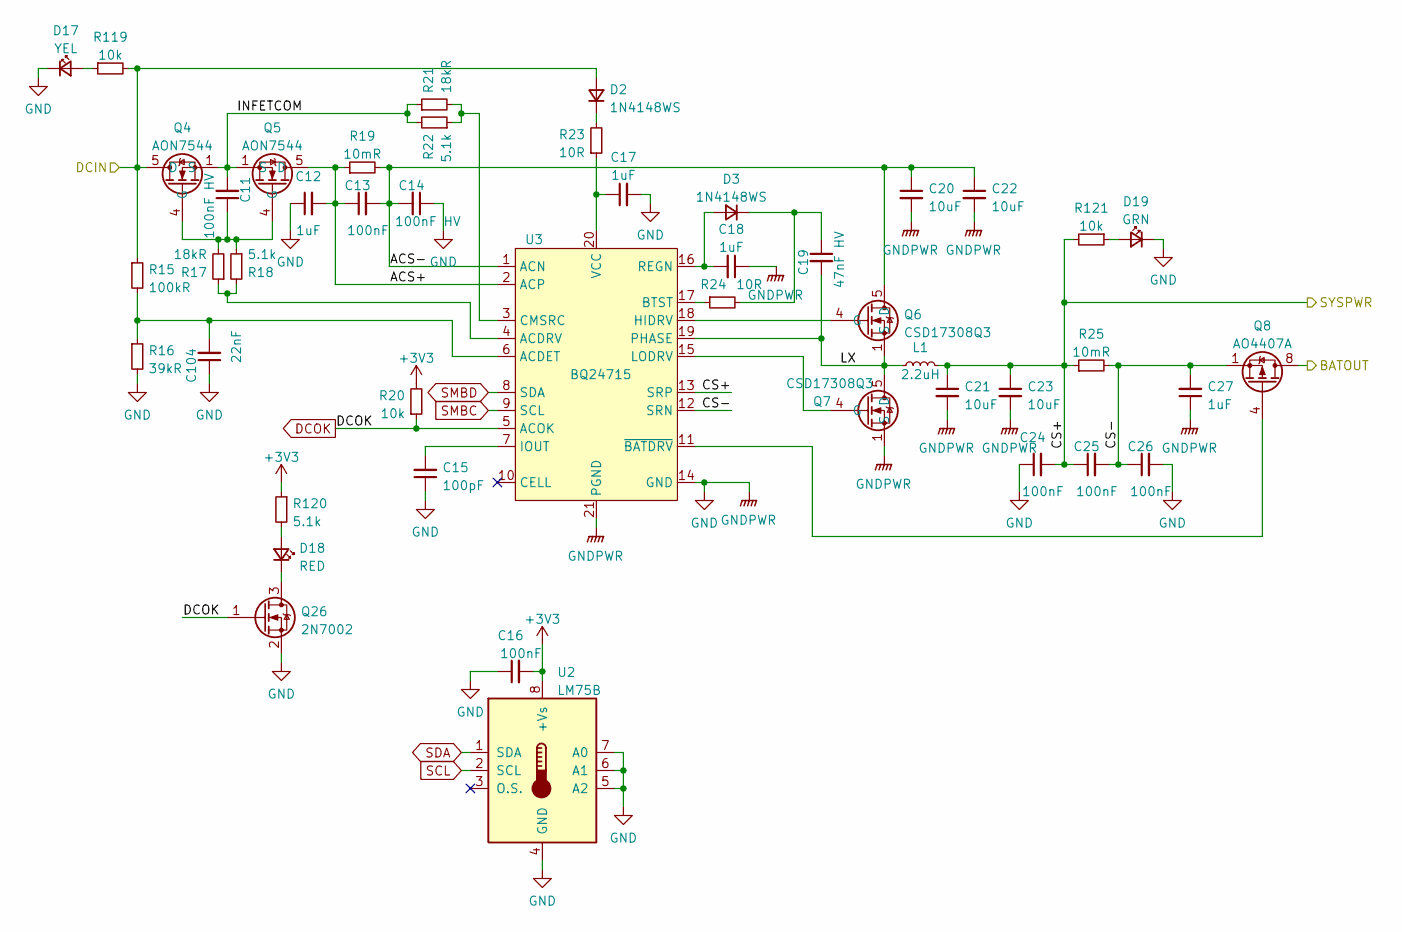
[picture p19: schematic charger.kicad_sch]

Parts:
C11, C14: 100nF HV; C_0603_1608Metric; LCSC C14663
C12, C17, C18, C27: 1uF; C_0402_1005Metric; LCSC C52923
C13, C16, C24, C25, C26: 100nF; C_0402_1005Metric; LCSC C1525
C15: 100pF; C_0402_1005Metric; LCSC C1546
C19: 47nF HV; C_0603_1608Metric; LCSC C1622
C20, C21, C22, C23: 10uF; C_0805_2012Metric; LCSC C15850
C104: 22nF; C_0402_1005Metric; LCSC C1532
D2, D3: 1N4148WS; D_SOD-323; LCSC C2128
D17: YEL; LED_0603_1608Metric; LCSC C72038
D18: RED; LED_0603_1608Metric; LCSC C2286
D19: GRN; LED_0603_1608Metric; LCSC C72043
L1: 2.2uH; L_Taiyo-Yuden_MD-4040; LCSC C98361
Q4, Q5: AON7544; DFN-8-FET_3x3mm_P0.65mm; LCSC C315567
Q6, Q7: CSD17308Q3; DFN-8-FET_3x3mm_P0.65mm; LCSC C294987
Q8: AO4407A; SOIC-8_3.9x4.9mm_P1.27mm; LCSC C167517
Q26: 2N7002; SOT-23; LCSC C8545
R15: 100kR; R_0402_1005Metric; LCSC C25741
R16: 39kR; R_0402_1005Metric; LCSC C25783
R17, R21: 18kR; R_0402_1005Metric; LCSC C25762
R18, R22, R120: 5.1k; R_0402_1005Metric; LCSC C25905
R19, R25: 10mR; R_0805_2012Metric; LCSC C270927
R20, R119, R121: 10k; R_0402_1005Metric; LCSC C25744
R23, R24: 10R; R_0402_1005Metric; LCSC C25077
U2: LM75B; MSOP-8_3x3mm_P0.65mm; LCSC C2837470
U3: BQ24715; QFN-20-1EP_3.5x3.5mm_P0.5mm_EP2x2mm_ThermalVias; LCSC C276341

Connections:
/Battery Pack/BAT+: Q8.5 (D), Q8.6 (D), Q8.7 (D), Q8.8 (D); also elsewhere on the board
/Charger/ACS+: C12.2, C13.1, Q5.5 (D), Q5.6 (D), Q5.7 (D), Q5.8 (D), Q5.9 (D), R19.1, U3.2 (ACP)
/Charger/ACS-: C13.2, C14.2, C20.1, C22.1, Q6.5 (D), Q6.6 (D), Q6.7 (D), Q6.8 (D), Q6.9 (D), R19.2, U3.1 (ACN)
/Charger/CS+: C21.1, C23.1, C24.2, C25.1, L1.2, R25.1, R121.2, U3.13 (SRP); also elsewhere on the board
/Charger/CS-: C25.2, C26.1, C27.2, Q8.1 (S), Q8.2 (S), Q8.3 (S), R25.2, U3.12 (SRN)
/Charger/DCIN: D2.2 (A), Q4.5 (D), Q4.6 (D), Q4.7 (D), Q4.8 (D), Q4.9 (D), R15.1, R119.2; also elsewhere on the board
/Charger/INFETCOM: C11.2, Q4.1 (S), Q4.2 (S), Q4.3 (S), Q5.1 (S), Q5.2 (S), Q5.3 (S), R21.1, R22.2
/Charger/LX: C19.2, L1.1, Q6.1 (S), Q6.2 (S), Q6.3 (S), Q7.5 (D), Q7.6 (D), Q7.7 (D), Q7.8 (D), Q7.9 (D), U3.19 (PHASE)
DCOK: Q26.1 (G), R20.1, U3.5 (ACOK); also elsewhere on the board
unnamed: D2.1 (K), R23.2
unnamed: C18.2, D3.2 (A), U3.16 (REGN)
unnamed: C19.1, D3.1 (K), R24.2
unnamed: D17.2 (A), R119.1
unnamed: D18.2 (A), R120.2
unnamed: D18.1 (K), Q26.3 (D)
unnamed: D19.2 (A), R121.1
unnamed: C11.1, Q4.4 (G), Q5.4 (G), R17.2, R18.1
unnamed: Q6.4 (G), U3.18 (HIDRV)
unnamed: Q7.4 (G), U3.15 (LODRV)
unnamed: Q8.4 (G), U3.11 (~BATDRV)
unnamed: C104.2, R15.2, R16.1, U3.6 (ACDET)
unnamed: R17.1, R18.2, U3.4 (ACDRV)
unnamed: R24.1, U3.17 (BTST)
unnamed: R21.2, R22.1, U3.3 (CMSRC)
unnamed: C15.2, U3.7 (IOUT)
unnamed: C17.1, R23.1, U3.20 (VCC)
SCL: U2.2 (SCL); also elsewhere on the board
SDA: U2.1 (SDA); also elsewhere on the board
SMBC: U3.9 (SCL); also elsewhere on the board
SMBD: U3.8 (SDA); also elsewhere on the board

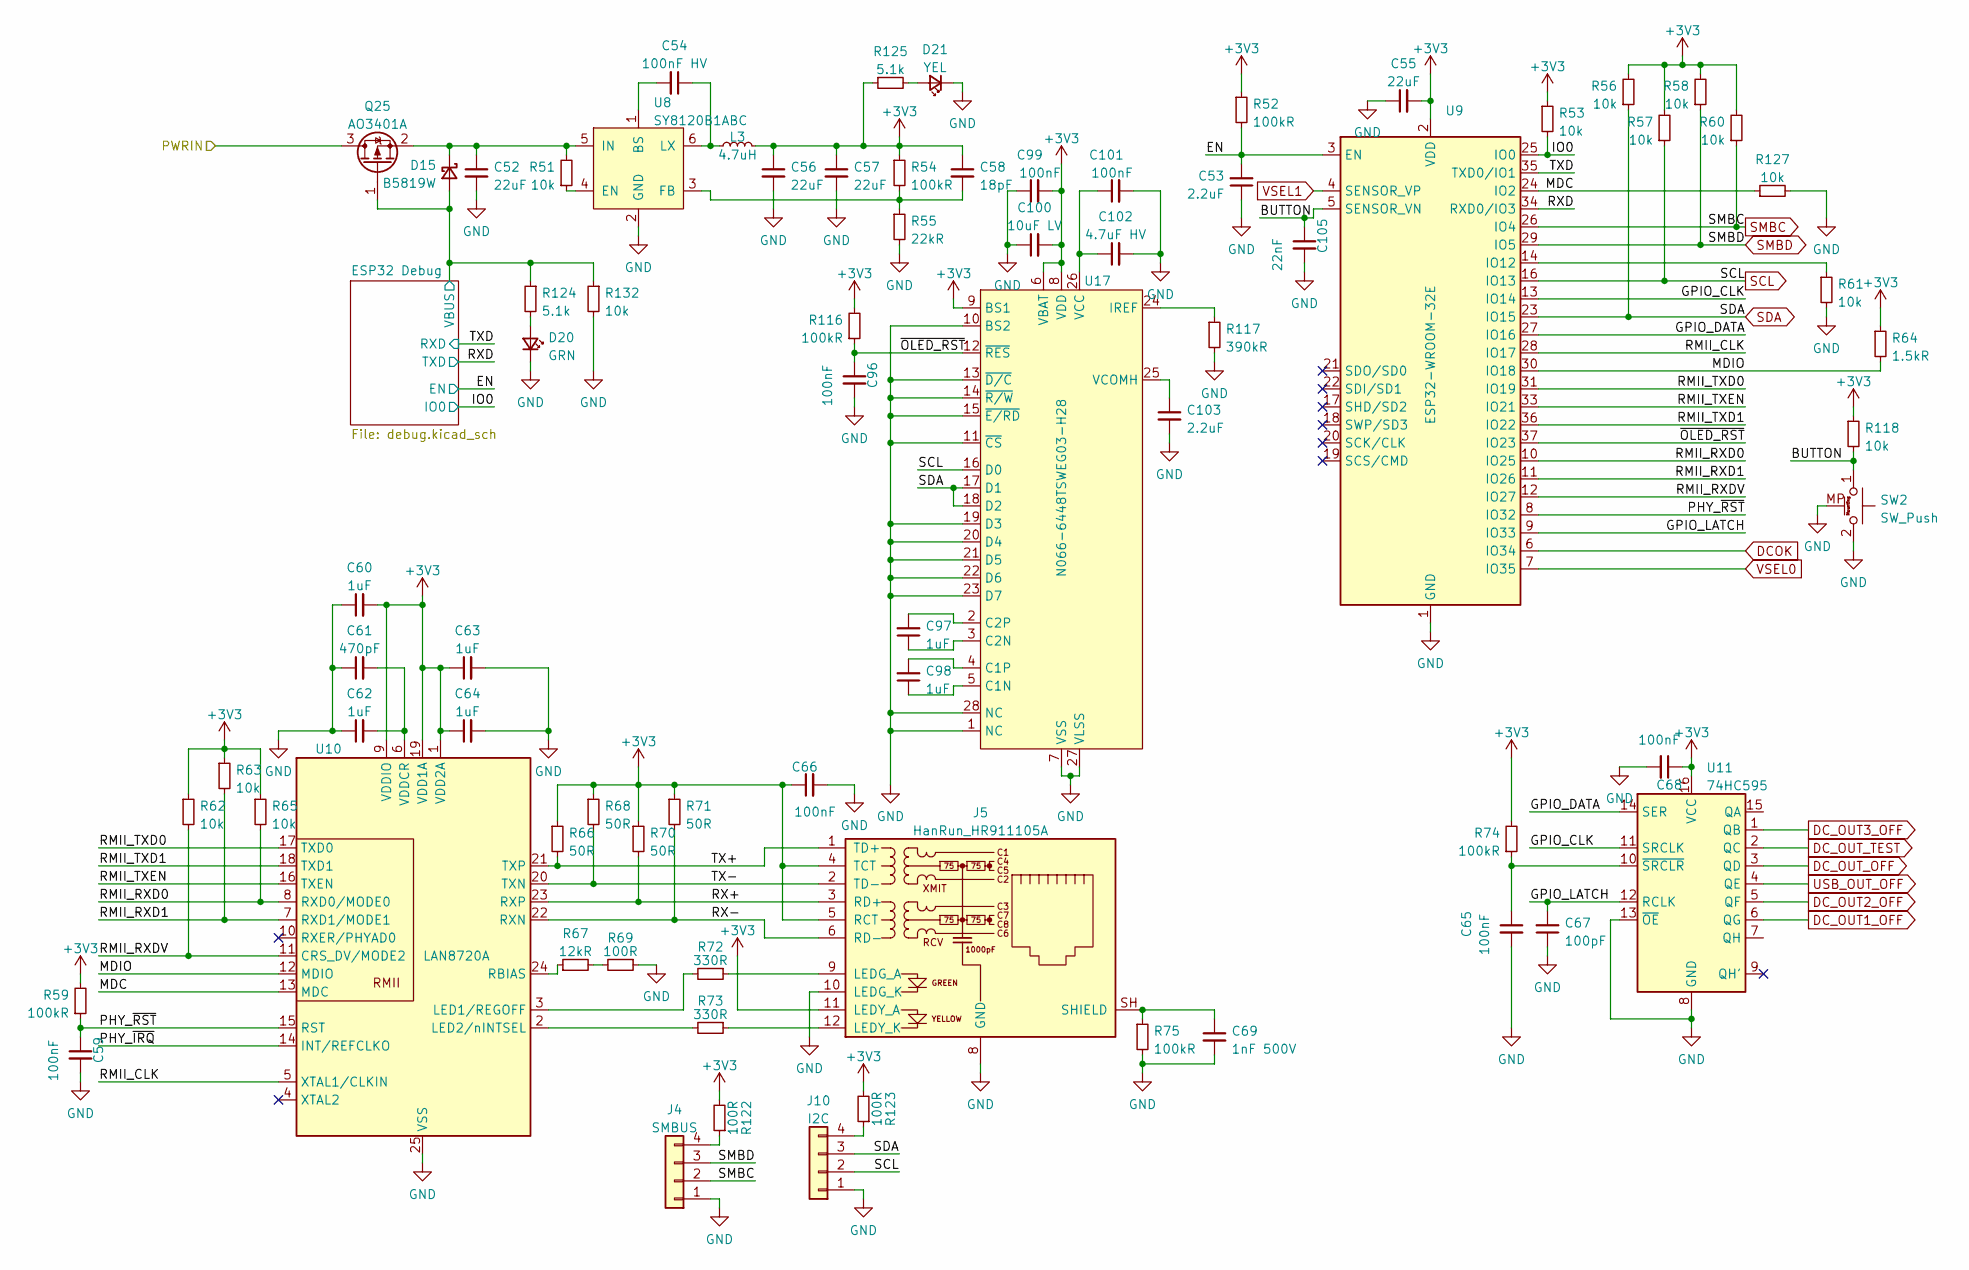
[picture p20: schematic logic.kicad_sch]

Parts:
C52, C55, C56, C57: 22uF; C_0805_2012Metric; LCSC C602037
C53, C103: 2.2uF; C_0603_1608Metric; LCSC C23630
C54: 100nF HV; C_0603_1608Metric; LCSC C14663
C58: 18pF; C_0402_1005Metric; LCSC C1549
C59, C65, C66, C68, C96, C99, C101: 100nF; C_0402_1005Metric; LCSC C1525
C60, C62, C63, C64, C97, C98: 1uF; C_0402_1005Metric; LCSC C52923
C61: 470pF; R_0402_1005Metric; LCSC C1537
C67: 100pF; C_0402_1005Metric; LCSC C1546
C69: 1nF 500V; C_1206_3216Metric; LCSC C35216
C100: 10uF LV; C_0402_1005Metric; LCSC C15525
C102: 4.7uF HV; C_0603_1608Metric; LCSC C19666
C105: 22nF; C_0402_1005Metric; LCSC C1532
D15: B5819W; D_SOD-123; LCSC C8598
D20: GRN; LED_0603_1608Metric; LCSC C72043
D21: YEL; LED_0603_1608Metric; LCSC C72038
J4: SMBUS; PinHeader_1x04_P2.54mm_Vertical
J5: HanRun_HR911105A; RJ45_Hanrun_HR911105A; LCSC C12074
J10: I2C; PinHeader_1x04_P2.54mm_Vertical
L3: 4.7uH; L_1008_2520Metric; LCSC C91237
Q25: AO3401A; SOT-23; LCSC C15127
R51, R53, R56, R57, R58, R60, R61, R62, R63, R65, R118, R127, R132: 10k; R_0402_1005Metric; LCSC C25744
R52, R54, R59, R74, R116: 100kR; R_0402_1005Metric; LCSC C25741
R55: 22kR; R_0402_1005Metric; LCSC C25768
R64: 1.5kR; R_0402_1005Metric; LCSC C25867
R66, R68, R70, R71: 50R; R_0402_1005Metric; LCSC C25120
R67: 12kR; R_0402_1005Metric; LCSC C25752
R69, R122, R123: 100R; R_0402_1005Metric; LCSC C25076
R72, R73: 330R; R_0402_1005Metric; LCSC C25104
R75: 100kR; R_1206_3216Metric; LCSC C17900
R117: 390kR; R_0603_1608Metric; LCSC C23150
R124, R125: 5.1k; R_0402_1005Metric; LCSC C25905
SW2: SW_Push; x-1825027-x; LCSC C266183
U8: SY8120B1ABC; SOT-23-6; LCSC C88474
U9: ESP32-WROOM-32E; ESP32-WROOM-32; LCSC C701342
U10: LAN8720A; QFN-24-1EP_4x4mm_P0.5mm_EP2.6x2.6mm; LCSC C45223
U11: 74HC595; SOIC-16_3.9x9.9mm_P1.27mm; LCSC C5947
U17: N066-6448TSWEG03-H28; LCSC C2890608

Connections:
/Charger/CS+: Q25.3 (D); also elsewhere on the board
/Control Logic/BUTTON: C105.1, R118.2, SW2.1, U9.5 (SENSOR_VN)
/Control Logic/EN: C53.2, R52.2, U9.3 (EN); also elsewhere on the board
/Control Logic/GPIO_CLK: U9.13 (IO14), U11.11 (SRCLK)
/Control Logic/GPIO_DATA: U9.27 (IO16), U11.14 (SER)
/Control Logic/GPIO_LATCH: C67.2, U9.9 (IO33), U11.12 (RCLK)
/Control Logic/IO0: R53.2, U9.25 (IO0); also elsewhere on the board
/Control Logic/MDC: R127.1, U9.24 (IO2), U10.13 (MDC)
/Control Logic/MDIO: R64.2, U9.30 (IO18), U10.12 (MDIO)
/Control Logic/PHY_~IRQ: U10.14 (INT/REFCLKO)
/Control Logic/PHY_~RST: C59.1, R59.1, U9.8 (IO32), U10.15 (RST)
/Control Logic/RMII_CLK: U9.28 (IO17), U10.5 (XTAL1/CLKIN)
/Control Logic/RMII_RXD0: R65.2, U9.10 (IO25), U10.8 (RXD0/MODE0)
/Control Logic/RMII_RXD1: R63.2, U9.11 (IO26), U10.7 (RXD1/MODE1)
/Control Logic/RMII_TXD0: U9.31 (IO19), U10.17 (TXD0)
/Control Logic/RMII_TXD1: U9.36 (IO22), U10.18 (TXD1)
/Control Logic/RMII_TXEN: U9.33 (IO21), U10.16 (TXEN)
/Control Logic/RX+: J5.3 (RD+), R70.2, U10.23 (RXP)
/Control Logic/RX-: J5.6 (RD-), R71.2, U10.22 (RXN)
/Control Logic/RXD: U9.34 (RXD0/IO3); also elsewhere on the board
/Control Logic/TX+: J5.1 (TD+), R66.2, U10.21 (TXP)
/Control Logic/TX-: J5.2 (TD-), R68.2, U10.20 (TXN)
/Control Logic/TXD: U9.35 (TXD0/IO1); also elsewhere on the board
/Control Logic/~OLED_RST: C96.1, R116.1, U9.37 (IO23), U17.12 (~RES)
DCOK: U9.6 (IO34); also elsewhere on the board
DC_OUT1_OFF: U11.6 (QG); also elsewhere on the board
DC_OUT2_OFF: U11.5 (QF); also elsewhere on the board
DC_OUT3_OFF: U11.1 (QB); also elsewhere on the board
DC_OUT_OFF: U11.3 (QD); also elsewhere on the board
DC_OUT_TEST: U11.2 (QC); also elsewhere on the board
unnamed: C52.1, D15.1 (K), Q25.2 (S), R51.2, U8.5 (IN)
unnamed: D20.2 (A), R124.2
unnamed: D21.2 (A), R125.2
unnamed: J4.4, R122.1
unnamed: J5.9 (LEDG_A), R72.1
unnamed: J5.12 (LEDY_K), R73.1
unnamed: C69.1, J5.SH (SHIELD), R75.1
unnamed: J10.4, R123.1
unnamed: R67.2, R69.2
unnamed: C54.2, U8.1 (BS)
unnamed: R51.1, U8.4 (EN)
unnamed: C58.2, R54.2, R55.1, U8.3 (FB)
unnamed: C54.1, L3.1, U8.6 (LX)
unnamed: R61.1, U9.14 (IO12)
unnamed: R72.2, U10.3 (LED1/REGOFF)
unnamed: R73.2, U10.2 (LED2/nINTSEL)
unnamed: R67.1, U10.24 (RBIAS)
unnamed: C61.2, C62.2, U10.6 (VDDCR)
unnamed: C65.1, R74.1, U11.10 (~SRCLR)
unnamed: C98.1, U17.5 (C1N)
unnamed: C98.2, U17.4 (C1P)
unnamed: C97.1, U17.3 (C2N)
unnamed: C97.2, U17.2 (C2P)
unnamed: R117.1, U17.24 (IREF)
unnamed: C101.1, C102.1, U17.26 (VCC)
unnamed: C103.1, U17.25 (VCOMH)
SCL: J10.2, R57.1, U9.16 (IO13), U17.16 (D0); also elsewhere on the board
SDA: J10.3, R56.1, U9.23 (IO15), U17.17 (D1), U17.18 (D2); also elsewhere on the board
SMBC: J4.2, R60.1, U9.26 (IO4); also elsewhere on the board
SMBD: J4.3, R58.1, U9.29 (IO5); also elsewhere on the board
USB_OUT_OFF: U11.4 (QE); also elsewhere on the board
VBUS: D15.2 (A), Q25.1 (G), R124.1, R132.1; also elsewhere on the board
VSEL0: U9.7 (IO35); also elsewhere on the board
VSEL1: U9.4 (SENSOR_VP); also elsewhere on the board

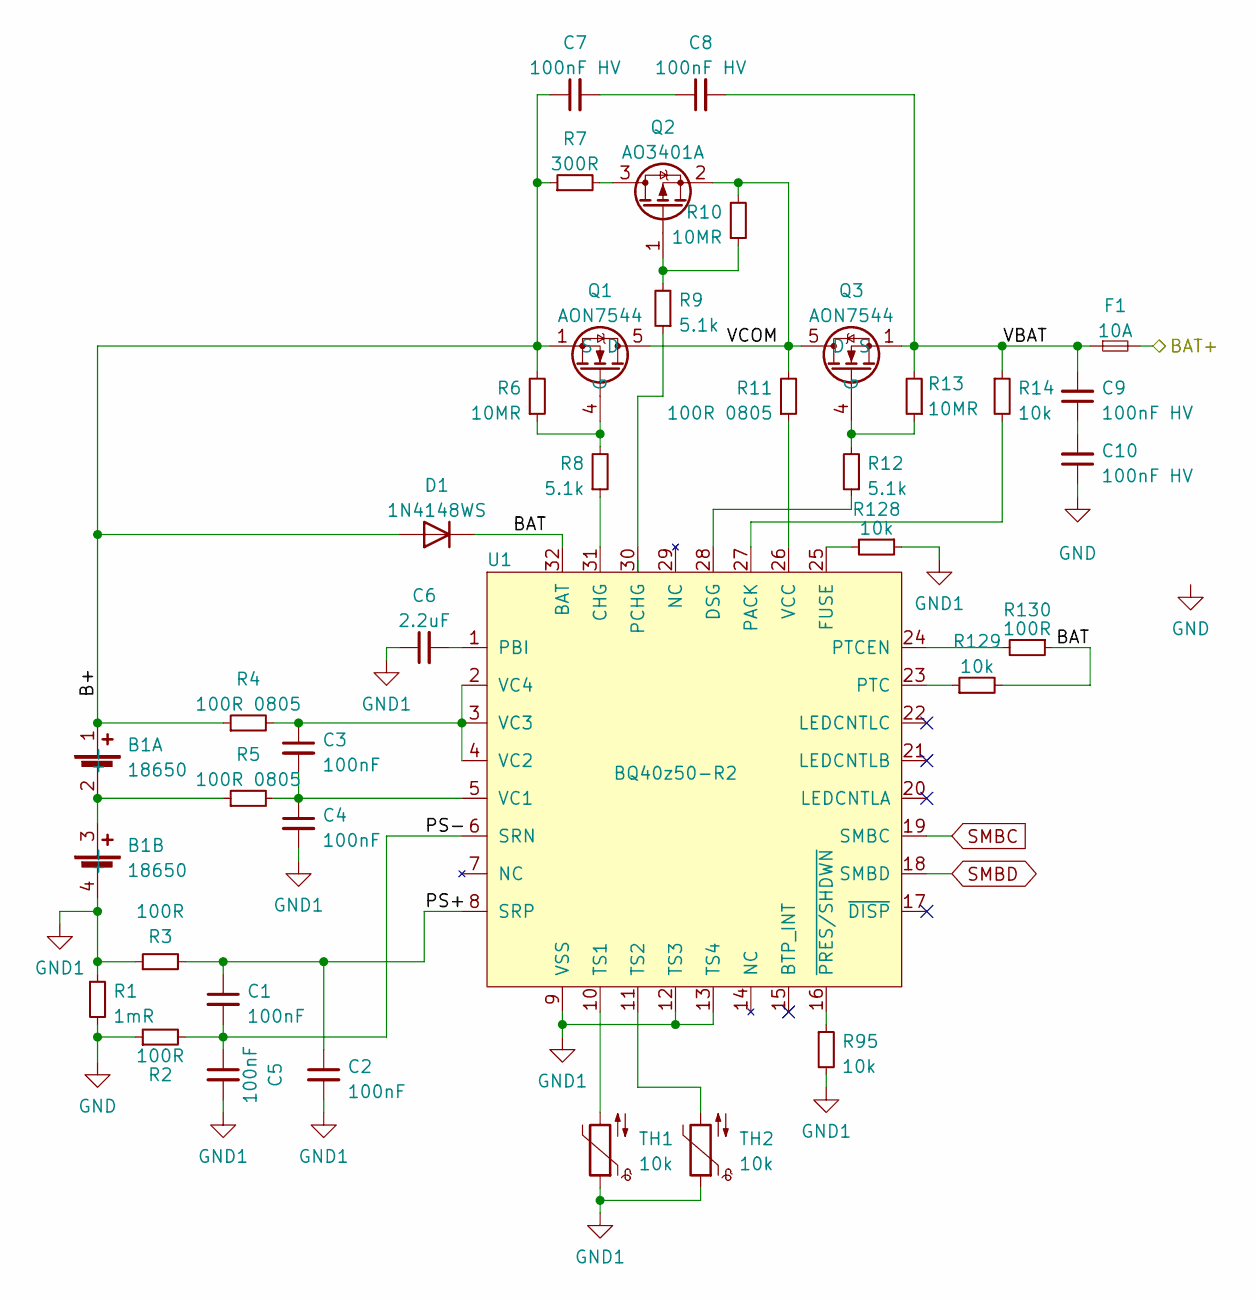
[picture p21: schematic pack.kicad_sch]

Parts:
B1: 18650; SMD-1048-dual-18650
C1, C2, C3, C4, C5: 100nF; C_0402_1005Metric; LCSC C1525
C6: 2.2uF; C_0603_1608Metric; LCSC C23630
C7, C8, C9, C10: 100nF HV; C_0603_1608Metric; LCSC C14663
D1: 1N4148WS; D_SOD-323; LCSC C2128
F1: 10A; Fuse_1206_3216Metric; LCSC C242475
Q1, Q3: AON7544; DFN-8-FET_3x3mm_P0.65mm; LCSC C315567
Q2: AO3401A; SOT-23; LCSC C15127
R1: 1mR; R_1206_3216Metric; LCSC C76287
R2, R3, R130: 100R; R_0402_1005Metric; LCSC C25076
R4, R5, R11: 100R 0805; R_0805_2012Metric; LCSC C17408
R6, R10, R13: 10MR; R_0402_1005Metric; LCSC C26082
R7: 300R; R_1206_3216Metric; LCSC C17887
R8, R9, R12: 5.1k; R_0402_1005Metric; LCSC C25905
R14, R95, R128, R129: 10k; R_0402_1005Metric; LCSC C25744
TH1, TH2: 10k; R_0402_1005Metric; LCSC C279801
U1: BQ40z50-R2; VQFN-32-4.1x4.1-EP-1.4; LCSC C179743

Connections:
/Battery Pack/B+: B1.1 (+), C7.1, D1.2 (A), Q1.1 (S), Q1.2 (S), Q1.3 (S), R4.1, R6.2, R7.1
/Battery Pack/BAT: D1.1 (K), R129.2, R130.1, U1.32 (BAT)
/Battery Pack/BAT+: F1.2; also elsewhere on the board
/Battery Pack/PS+: C1.1, C2.1, R3.2, U1.8 (SRP)
/Battery Pack/PS-: C1.2, C5.1, R2.2, U1.6 (SRN)
/Battery Pack/VBAT: C8.2, C9.2, F1.1, Q3.1 (S), Q3.2 (S), Q3.3 (S), R13.2, R14.1
/Battery Pack/VCOM: Q1.5 (D), Q1.6 (D), Q1.7 (D), Q1.8 (D), Q1.9 (D), Q2.2 (S), Q3.5 (D), Q3.6 (D), Q3.7 (D), Q3.8 (D), Q3.9 (D), R10.2, R11.2
GND1: B1.4 (-), C2.2, C4.2, C5.2, C6.1, R1.1, R3.1, R95.2, R128.1, TH1.1, TH2.1, U1.9 (VSS), U1.12 (TS3), U1.13 (TS4), U1.33 (PWRPD)
unnamed: B1.2 (-), B1.3 (+), R5.1
unnamed: C7.2, C8.1
unnamed: C9.1, C10.2
unnamed: Q1.4 (G), R6.1, R8.2
unnamed: Q2.3 (D), R7.2
unnamed: Q2.1 (G), R9.2, R10.1
unnamed: Q3.4 (G), R12.2, R13.1
unnamed: R8.1, U1.31 (CHG)
unnamed: R12.1, U1.28 (DSG)
unnamed: R128.2, U1.25 (FUSE)
unnamed: R14.2, U1.27 (PACK)
unnamed: C6.2, U1.1 (PBI)
unnamed: R9.1, U1.30 (PCHG)
unnamed: R129.1, U1.23 (PTC)
unnamed: R130.2, U1.24 (PTCEN)
unnamed: TH1.2, U1.10 (TS1)
unnamed: TH2.2, U1.11 (TS2)
unnamed: C3.2, C4.1, R5.2, U1.5 (VC1)
unnamed: C3.1, R4.2, U1.2 (VC4), U1.3 (VC3), U1.4 (VC2)
unnamed: R11.1, U1.26 (VCC)
unnamed: R95.1, U1.16 (~PRES/SHDWN)
SMBC: U1.19 (SMBC); also elsewhere on the board
SMBD: U1.18 (SMBD); also elsewhere on the board

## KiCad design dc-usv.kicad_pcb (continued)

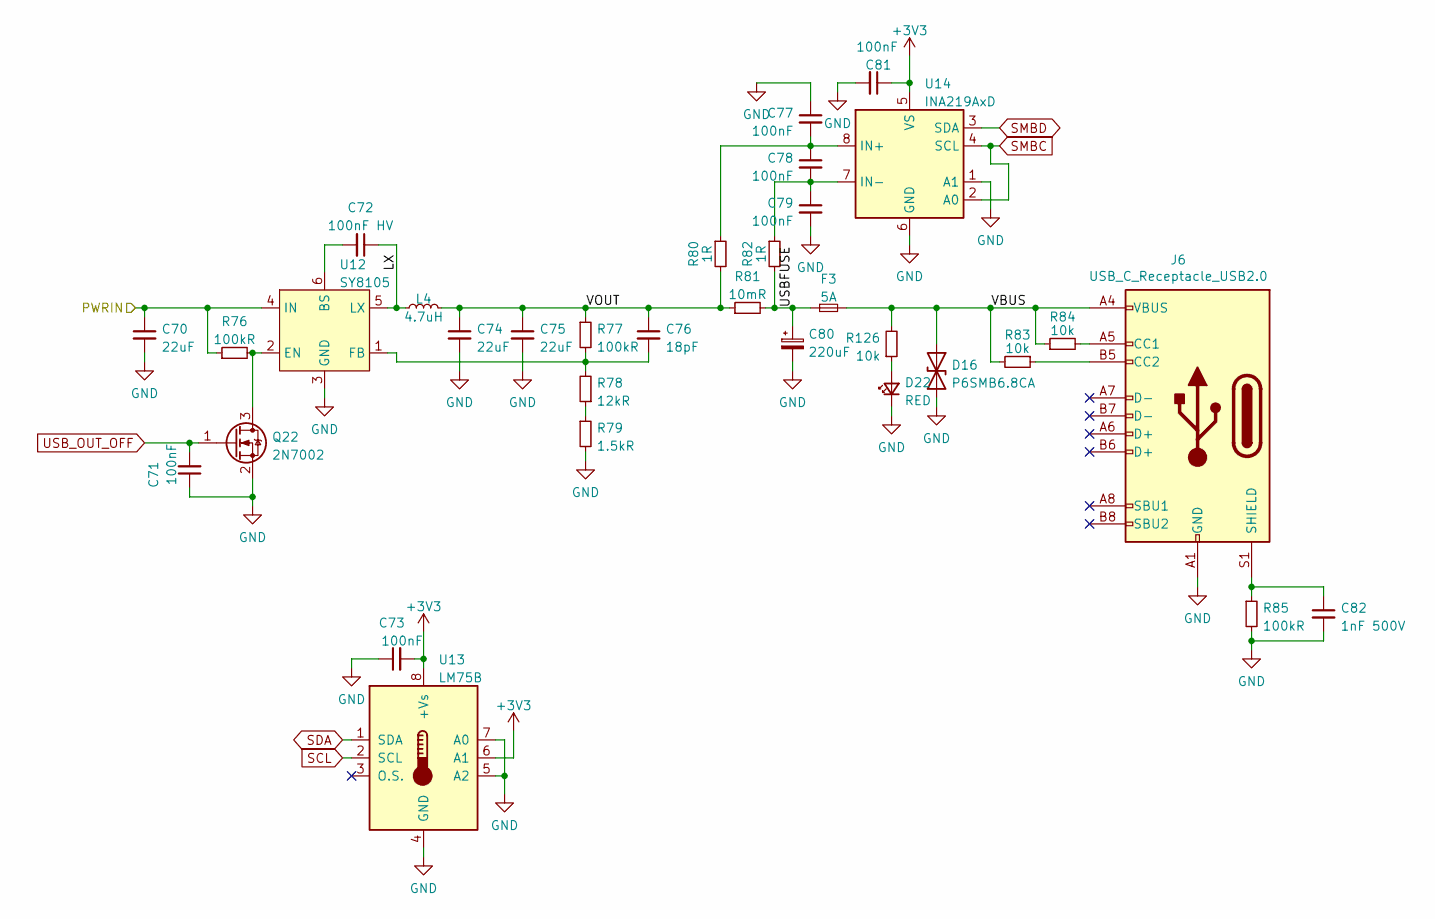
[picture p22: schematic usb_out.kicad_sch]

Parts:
C70, C74, C75: 22uF; C_0805_2012Metric; LCSC C602037
C71, C73, C77, C78, C79, C81: 100nF; C_0402_1005Metric; LCSC C1525
C72: 100nF HV; C_0603_1608Metric; LCSC C14663
C76: 18pF; C_0402_1005Metric; LCSC C1549
C80: 220uF; CP_Elec_6.3x7.7; LCSC C340768
C82: 1nF 500V; C_1206_3216Metric; LCSC C35216
D16: P6SMB6.8CA; D_SMB; LCSC C78395
D22: RED; LED_0603_1608Metric; LCSC C2286
F3: 5A; Fuse_1206_3216Metric; LCSC C377290
J6: USB_C_Receptacle_USB2.0; USB_C_Receptacle_Palconn_UTC16-G; LCSC C167321
L4: 4.7uH; L_Bourns_SRP7028A_7.3x6.6mm; LCSC C76857
Q22: 2N7002; SOT-23; LCSC C8545
R76, R77: 100kR; R_0402_1005Metric; LCSC C25741
R78: 12kR; R_0402_1005Metric; LCSC C25752
R79: 1.5kR; R_0402_1005Metric; LCSC C25867
R80, R82: 1R; R_0402_1005Metric; LCSC C25086
R81: 10mR; R_0805_2012Metric; LCSC C270927
R83, R84, R126: 10k; R_0402_1005Metric; LCSC C25744
R85: 100kR; R_1206_3216Metric; LCSC C17900
U12: SY8105; TSOT-23-6; LCSC C178247
U13: LM75B; MSOP-8_3x3mm_P0.65mm; LCSC C2837470
U14: INA219AxD; SOIC-8_3.9x4.9mm_P1.27mm; LCSC C138706

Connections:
/Charger/CS+: C70.1, R76.1, U12.4 (IN); also elsewhere on the board
/USB Output/LX: C72.1, L4.1, U12.5 (LX)
/USB Output/USBFUSE: C80.1, F3.1, R81.2, R82.2
/USB Output/VBUS: D16.1 (A1), F3.2, J6.A4 (VBUS), J6.A9 (VBUS), J6.B4 (VBUS), J6.B9 (VBUS), R83.2, R84.1, R126.2
/USB Output/VOUT: C74.1, C75.1, C76.1, L4.2, R77.1, R80.2, R81.1
unnamed: D22.2 (A), R126.1
unnamed: J6.A5 (CC1), R84.2
unnamed: J6.B5 (CC2), R83.1
unnamed: C82.1, J6.S1 (SHIELD), R85.1
unnamed: Q22.3 (D), R76.2, U12.2 (EN)
unnamed: R78.1, R79.1
unnamed: C72.2, U12.6 (BS)
unnamed: C76.2, R77.2, R78.2, U12.1 (FB)
unnamed: C77.2, C78.1, R80.1, U14.8 (IN+)
unnamed: C78.2, C79.1, R82.1, U14.7 (IN-)
SCL: U13.2 (SCL); also elsewhere on the board
SDA: U13.1 (SDA); also elsewhere on the board
SMBC: U14.2 (A0), U14.4 (SCL); also elsewhere on the board
SMBD: U14.3 (SDA); also elsewhere on the board
USB_OUT_OFF: C71.2, Q22.1 (G); also elsewhere on the board

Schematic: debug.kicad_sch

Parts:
C89: 1nF 500V; C_1206_3216Metric; LCSC C35216
C90, C91: 20pF; C_0402_1005Metric; LCSC C1554
C92, C93: 100nF; C_0402_1005Metric; LCSC C1525
D7: P6SMB6.8CA; D_SMB; LCSC C78395
J9: USB_C_Receptacle_USB2.0; USB_C_Receptacle_Palconn_UTC16-G; LCSC C167321
Q28, Q29: MMBT3904; SOT-23; LCSC C20526
R96: 100kR; R_1206_3216Metric; LCSC C17900
R97, R98: 5.1k; R_0402_1005Metric; LCSC C25905
R99, R100: 100R; R_0402_1005Metric; LCSC C25076
R101, R102: 100kR; R_0402_1005Metric; LCSC C25741
U16: CH340C; SOIC-16_3.9x9.9mm_P1.27mm; LCSC C84681
U18: SRV05-4; SOT-23-6; LCSC C85364
Y1: 12MHz (DNP); Crystal_SMD_3225-4Pin_3.2x2.5mm; LCSC C9002

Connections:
/Control Logic/EN: Q28.3 (C); also elsewhere on the board
/Control Logic/IO0: Q29.3 (C); also elsewhere on the board
/Control Logic/RXD: R99.1; also elsewhere on the board
/Control Logic/TXD: R100.2; also elsewhere on the board
unnamed: J9.A5 (CC1), R97.2
unnamed: J9.B5 (CC2), R98.1
unnamed: C89.1, J9.S1 (SHIELD), R96.1
unnamed: Q28.1 (B), R101.2
unnamed: Q28.2 (E), R102.1, U16.14 (~RTS)
unnamed: Q29.1 (B), R102.2
unnamed: Q29.2 (E), R101.1, U16.13 (~DTR)
unnamed: R100.1, U16.3 (RXD)
unnamed: R99.2, U16.2 (TXD)
unnamed: J9.A6 (D+), J9.B6 (D+), U16.5 (UD+), U18.4 (IO3)
unnamed: J9.A7 (D-), J9.B7 (D-), U16.6 (UD-), U18.6 (IO4)
unnamed: C90.2, U16.7 (XI), Y1.1
unnamed: C91.1, U16.8 (XO), Y1.3
VBUS: D7.2 (A2), J9.A4 (VBUS), J9.A9 (VBUS), J9.B4 (VBUS), J9.B9 (VBUS), U18.5 (VP); also elsewhere on the board

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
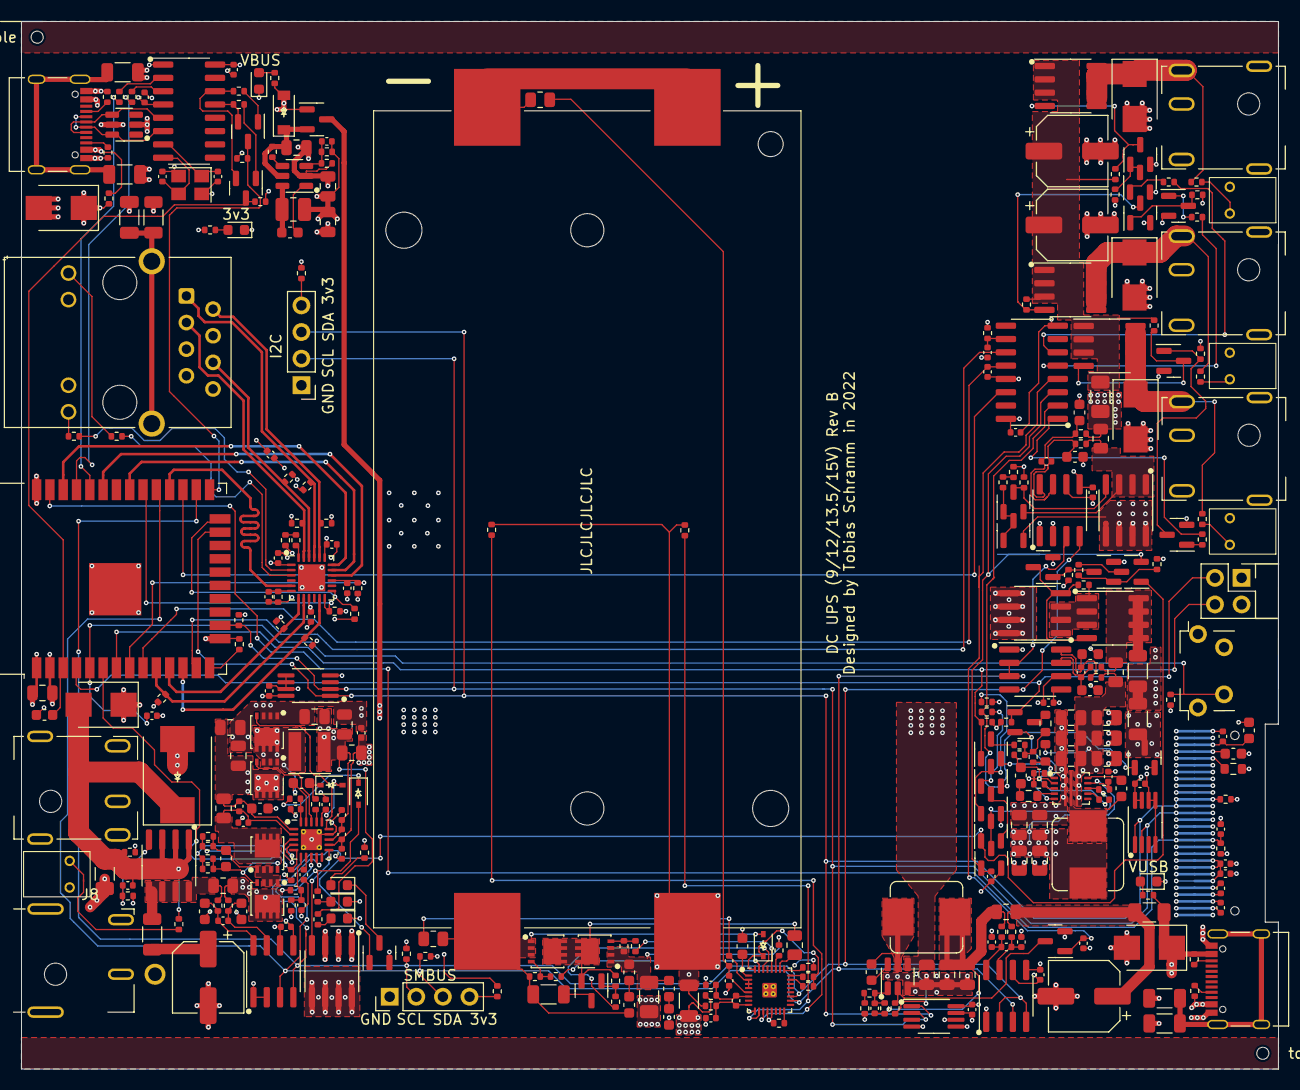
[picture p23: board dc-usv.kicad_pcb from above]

Board: 4 copper layers, 120.0 x 100.0 mm, 342 parts (1 on the bottom side), 202 nets.

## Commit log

2022-09-19 Add partial DC output circuitry
    [dc-usv.kicad_sch, dc_in.kicad_sch, logic.kicad_sch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]
2022-09-20 Finish DC output schematic capture
    [dc-usv.kicad_sch, dc_in.kicad_sch, dc_out.kicad_sch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]
2022-09-20 Add barrel jack footprints
    [charger.kicad_sch, dc-usv.kicad_sch, dc_in.kicad_sch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]
2022-09-20 Add individually switchable outputs
    [charger.kicad_sch, dc-usv.kicad_pcb, dc-usv.kicad_sch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]
2022-09-21 Charger and step-down component placement
    [dc-usv.kicad_pcb, dc-usv.kicad_sch, logic.kicad_sch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]
2022-09-21 Partial DC out step-up component placement
    [dc-usv.kicad_pcb, dc-usv.kicad_sch, usb_out.kicad_sch]
2022-09-21 Finish step-up component placement and partial layout
    [dc-usv.kicad_pcb, dc-usv.kicad_sch, output.kicad_sch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]
2022-09-21 Add 64x48 SSD1306 OLED
    [dc-usv.kicad_pcb, dc-usv.kicad_sch, logic.kicad_sch]
2022-09-22 Plan front panel element positioning
    [dc-usv.kicad_pcb, dc-usv.kicad_sch, logic.kicad_sch]
2022-09-23 Partial layout
    [charger.kicad_sch, dc-usv.kicad_pcb, dc-usv.kicad_sch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]
2022-09-23 Partial DC out component placement
    [dc-usv.kicad_pcb]
2022-09-25 Finish initial layout
    [dc-usv.kicad_pcb, logic.kicad_sch, output.kicad_sch]
2022-09-25 Add debouncing capacitor to front panel button
    [dc-usv.kicad_pcb, dc-usv.kicad_sch, logic.kicad_sch]
2022-09-25 Optimize power routing
    [dc-usv.kicad_pcb, output.kicad_sch]
2022-09-25 Add SMBUS and I2C debug headers
    [dc-usv.kicad_pcb, dc-usv.kicad_sch, logic.kicad_sch]
2022-09-25 Hide silkscreen designators
    [dc-usv.kicad_pcb]
2022-09-25 Thermal optimizations
    [dc-usv.kicad_pcb]
2022-09-25 Add component direction indicators
    [dc-usv.kicad_pcb]
2022-09-25 Add tooling holes
    [dc-usv.kicad_pcb, dc-usv.kicad_sch]
2022-09-25 Add thermal plane to SYSPWR MOSFET
    [dc-usv.kicad_pcb]
2022-09-25 Optimize thermal connectivity of USB output regulator
    [dc-usv.kicad_pcb]
2022-09-25 Add informational silkscreen designators
    [dc-usv.kicad_pcb]
2022-09-25 Add more voltage rail LEDs
    [dc-usv.kicad_pcb, dc-usv.kicad_sch, logic.kicad_sch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]
2022-09-25 Fix DRC errors
    [dc-usv.kicad_pcb]
2022-09-25 Fix footprint origins for JLC assembly
    [charger.kicad_sch, dc-usv.kicad_pcb, dc-usv.kicad_sch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]
2022-09-25 Adjust RMII clock to average electrical RMII signal length
    [dc-usv.kicad_pcb]
2022-09-25 Swap GPIO2 and GPIO23 to ensure UART download mode can be entered
    [dc-usv.kicad_pcb, dc-usv.kicad_sch, logic.kicad_sch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]
2022-09-25 Move front panel button further to PCB center
    Makes sure button does not stick out quite as far from front panel
    [dc-usv.kicad_pcb]
2022-09-25 Fix embarrassing typo
    [dc-usv.kicad_pcb]
2022-09-26 Fix incorrect part number on R32
    Previously chosen part had 0402 footprint, 0603 needed.
    [dc-usv.kicad_pcb, output.kicad_sch]
2022-09-27 Add frontpanel
    [frontpanel.kicad_pcb, frontpanel.kicad_sch]
2022-09-28 Add backpanel
    [backpanel.kicad_pcb, backpanel.kicad_sch, frontpanel.kicad_pcb]
2022-09-28 Add 3d models
    [backpanel.kicad_pcb, dc-usv.kicad_pcb, dc-usv.kicad_sch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]
2022-10-10 Fix reversed debug USB TVS
    [dc-usv.kicad_pcb, dc-usv.kicad_sch, debug.kicad_sch]
2022-10-16 Add FUSE pulldown and PTC dummy
    In contrast to documentation provided by TI FUSE is neither just an
    output nor does the PTCEN feature work as advertised.
    The FUSE pin contains a switchable 150nA current source. Presumably it
    is used as a safety to detect if the FUSE pin is open. Unfortunately the
    gauage will not allow control of the CHG, DSG and PRECHG FETs when it
    detects an open FUSE pin. There does not seem to be any configuration
    option for this behaviour either.
    The PTC pin allows connecting a PTC to detect overheating of the main
    power path control FETs. According to the BQ40Z50 datasheet it is possible
    to disable this safety function by tieing PTCEN to VSS. Unfortunately this
    does n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
    [dc-usv.kicad_pcb, dc-usv.kicad_sch, pack.kicad_sch]
2022-10-16 Fix gate discharge resistor on Q10
    The gate discharge resistor on Q10 was by mistake connected to drain
    instead of source.
    [dc-usv.kicad_pcb, dc-usv.kicad_sch, output.kicad_sch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]
2022-10-16 Add ase discharge resistor to Q18
    [dc-usv.kicad_pcb, dc-usv.kicad_sch, output.kicad_sch]
2022-10-16 Fix swapped gauage current sense pins
    [dc-usv.kicad_pcb, dc-usv.kicad_sch, output.kicad_sch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]
2022-10-16 Compensate leakage through VBUS schottky diode
    Add 10k resistor from VBUS to GND to compensate for schottky diode
    leakage.
    [dc-usv.kicad_pcb, dc-usv.kicad_sch, logic.kicad_sch]
2022-10-17 Add missing annotations
    [dc-usv.kicad_sch, logic.kicad_sch]
2022-10-17 Fix incorrect AO447A partnumber
    The previous partnumber was pointing to a N-Channel MOSFET.
    Use a P-Channel one.
    [charger.kicad_sch, dc-usv.kicad_pcb, dc_in.kicad_sch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]
2023-06-03 Rev 1.0 bugfixes
    Changes:
    - Replace DCOK-driven DC passthrough switch with ideal diode
    - Reduce INA219 series filter resistance to 1 ohm
    - Simplify debug USB power gating
    - Fix incorrect USB CC pullups
    [charger.kicad_sch, dc-usv.kicad_pcb, dc-usv.kicad_sch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]
2023-07-01 Sync PCB with schematic
    [dc-usv.kicad_pcb]
2023-07-01 Add RevB fabrication files
    [dc-usv.kicad_pcb, dc-usv_bom_jlc.csv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]
2023-07-01 Add more details to assembly section of readme
2023-09-08 Fix incorrectly referenced FET footprint library
2024-05-09 lib: update JLCPCB tooling footprints
    Add fiducials and mouse bites
2024-05-09 Fix remaining RevB bugs
    - DNP Q13 by default to ensure uninterrupted power power delivery
    - Use lower resistance load resistors for DC step-up selftest
    - Add edge rails to support JLCPCB standard assembly
    Unfortuantely JLCPCB does not seems to offer ESP32 WROOMs anymore for
    economic PCBA. Thus edge-rails have been added to support standard PCBA.
    [charger.kicad_sch, logic.kicad_sch, output.kicad_sch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]
2024-05-09 Add RevC fabrication files
    [dc-usv_bom_jlc.csv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]
2024-05-09 Fix aluminum case part number
